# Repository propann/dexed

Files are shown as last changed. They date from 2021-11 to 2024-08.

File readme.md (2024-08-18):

> NOTE: Microdexed-touch is capable of generating audio with a large dynamic range, the extremes of which can cause damage to loudspeakers or other components, and also to your hearing.
> Please be specially careful when activating the MultiBand Compressor. Depending on it's settings, this easily can increase the perceived output loudness by 10x or even more.

# MicroDexed-touch

<br><p>

<br>
(SLA PRINTED ENCLOSURE, DISPLAY SIZE LEFT: 2.8", MIDDLE: 2,8" and RIGHT: 3.2")
<br><p>

<br>
(PCB BASED FRONT/BACK PANEL, DISPLAY SIZE LEFT 2.8" and RIGHT 3.2")
<br><p>
## This is MicroDexed with TFT Touch Display, graphic UI and sequencer

### This build requires a Teensy 4.1,  PCM5102 Audio Board, 320x240 ILI9341 SPI Display with Capacitive Touchscreen, a serial Flash Chip  (and a PSRAM Chip for custom samples).
<p>

MicroDexed started as a Teensy based, 6-operator-FM-synthesizer. The first generation is still maintained at: [https://codeberg.org/dcoredump/MicroDexed](https://codeberg.org/dcoredump/MicroDexed)

Compared to the first generation, MicroDexed-touch offers a lot of new features/improvements:

* The Flash Chip is presoldered on a small PCB attachment for <2$.

* "Large" Graphical Interface, view and edit multiple Parameters in one Screen

* Use external MIDI gear over USB or Mini TRS Jacks (DIN MIDI with adaptor) from 2 x 16 MIDI Channels in the Sequencer

* Map MIDI CC to external MIDI Devices to control Input/Parameters

* Global plate reverb, 2 global delay effects (500ms, with added PSRAM chip 60 seconds or even more)

* Loading, playing and editing multi-sampled instruments or layered instruments in a "live" mode or played by the sequencer. Auto detection sample zones but also can be edited manually. This is early work in progress and currently not stable when using pitch shifting and polyphony

* 2 instances of "Virtual Analog" Monosynths with one OSC, PWM, Multimode Filter and Noise. A lot of useful new sound possibilities.

* 8 voice polyphonic Oscillator, based on the code of Mutable Instruments - Braids. No wavetables but added individual envelopes and multimode filters for all voices
 
* Much improved Sequencer with 8 Tracks, 16 Step Patterns, 16 Step Pattern Chains, up to 16384 Song Steps, Arpeggiator with 1/8 - 1/64 Steps, Arp Patterns including Euclidean settings, Pitched Drum- and Instrument Sample playback

* The sequencer can also play chords of various types, stacked up to 7 notes, using only a single sequencer track

* Global Mixer View with all Channels

* Multiband Master Compressor with 4 bands

* Sample Management from SD-CARD and SPI FLASH/PSRAM, samples can be loaded from SD-CARD to PSRAM during runtime.

* Touch Mute Matrix for live / realtime performance

* Tracker View (Editor) - work in progress

* Track Print/Recording - work in progress

* Remote control in web-based 1:1 UI with added features (filemanager,filetransfer, screenshots etc.) Work in progress - connected to PC via Teensy MicroUSB Connector

[https://www.youtube.com/watch?v=AkmqZVpW2Vg
](https://www.youtube.com/watch?v=AkmqZVpW2Vg)
by Floyd Steinberg
<br>
<p>

[Part1/2](https://www.youtube.com/watch?v=v6thf0vhRxU)
by fellpower (german language)

[Part2/2](https://www.youtube.com/watch?v=wfSquKaAqik)
by fellpower (german language)

### YouTube playlist about the development:
[https://www.youtube.com/playlist?list=PLHTypoMU1QoGOXPli8bjR6MknPiQpubHl
](https://www.youtube.com/playlist?list=PLHTypoMU1QoGOXPli8bjR6MknPiQpubHl)

## If you want to donate to this project, please check out this link:

<a href="https://liberapay.com/positionhigh/donate">Donate using Liberapay</a>

### User Chat groups

[https://discord.gg/XCYk5P8GzF](https://discord.gg/XCYk5P8GzF)

[https://matrix.to/#/#microdexed:matrix.org](https://matrix.to/#/#microdexed:matrix.org)

### PCB is available from PCBWAY

If you register and pay as a new user at PCBWAY with this Invite link, you should get $5 "New User Free Credit" - so you can order 5 PCB pieces for "free", except shipping and customs cost etc.
    
[https://www.pcbway.com/setinvite.aspx?inviteid=565384](https://www.pcbway.com/setinvite.aspx?inviteid=565384)

<a href="https://www.pcbway.com/project/shareproject/MicroDexed_Capacitive_Touch_64970fee.html">PCB from PCBWay</a>

<br>
<p>

## WIKI

Installation / BOM / Compile Instructions / 3D printer files / FAQ / Changelog / News / Troubleshooting etc.
<br>
[https://codeberg.org/positionhigh/MicroDexed-touch/wiki/?action=_pages](https://codeberg.org/positionhigh/MicroDexed-touch/wiki/?action=_pages)

## License

This is a port of the original Dexed/msfa engine (see https://github.com/asb2m10/dexed and https://github.com/google/music-synthesizer-for-android) to be used on a ~~Teensy-3.6 or~~ Teensy-4.1.

MicroDexed is licensed on the GPL v3. The msfa component (acronym for music synthesizer for android, see https://github.com/google/music-synthesizer-for-android) stays on the Apache 2.0 license to able to collaborate between projects.

## Buttons / Encoders

A quick guide how the push Encoders are working:

Usualy [SHORT PUSH] Encoder Left brings you back to the main menu or closer to the main menu one step.

Usualy [SHORT PUSH] Encoder Right selects or confirms an input/menu item/goes deeper into this item.

In most menu settings of dexed, [SHORT PUSH] Encoder Right, switches between the 2 dexed Instances.

In microsynth, [LONG PUSH] Encoder Right, switches between the 2 microsynth Instances.

in Voice select (dexed) : [SHORT PUSH] Encoder Right switches Instances, [LONG PUSH] Encoder Right switches betweens Banks and Sounds. [LONG PUSH] Encoder Left selects/unselects Sounds to the Favorites list.

In Menus that need 2 Encoders, Encoder Right controls Y movement and Encoder Left controls X movement
(for example in Song mode)

## CONTRIBUTING

This project lives from the contributions of C++ developers, testers, reviewers. Please check https://codeberg.org/positionhigh/MicroDexed-touch/issues to help in open topics or add your own Issue or Feature Request.

## SURVEY / POLL: Let us know what you want to see (manufacturing/building MDT)
[https://www.supersurvey.com/poll4335406x48364DD1-136](https://www.supersurvey.com/poll4335406x48364DD1-136)

## SURVEY / POLL 08/2024 feature requests:
[https://qvgopz6on.supersurvey.com/](https://qvgopz6on.supersurvey.com/)

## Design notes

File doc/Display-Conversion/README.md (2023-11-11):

This guide shows how to convert your PCB from resistive touch to capacitive Touch display.
    <br>
    <p> 
    
### SCHEMATICS

CUT all traces/connections shown in RED color.
ADD connections shown in GREEN with wires.
<br>

### SCHEMATICS
<br>

<br> Wiring of old and new display connector 
<p>
    
### PCB FRONT
<br>

<br>
Unfortunately it is required to remove the display connector to reach these 2 traces.
<br>
Use your favorite proven method, how to remove the connector. This could be hot air, a desoldering tool/gun or desoldering wick.
<br>
<p>

### PCB BACK

<br>

<br>
<p>

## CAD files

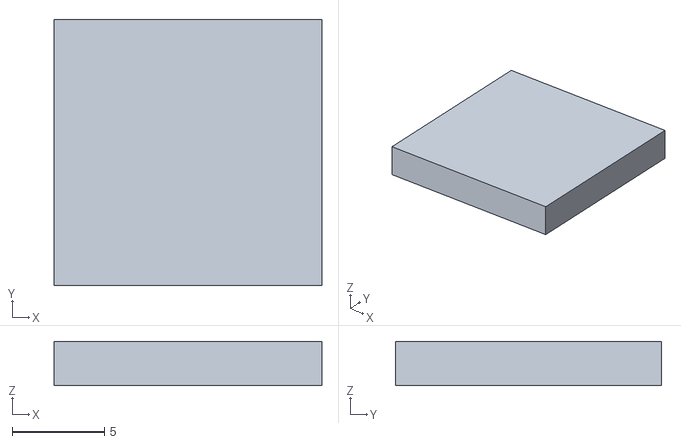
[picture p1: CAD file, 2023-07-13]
doc/Build_InstructionsV2/CASE-SDMOD-LID-COVER.stl
14.5 x 14.4 x 2.40

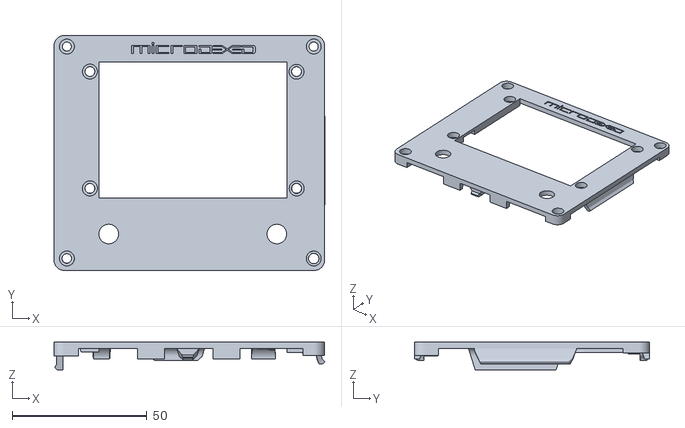
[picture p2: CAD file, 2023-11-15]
doc/Build_InstructionsV3_Capacitive_Touch/LID-capacitive_touch.stl
100.7 x 87.3 x 10.4

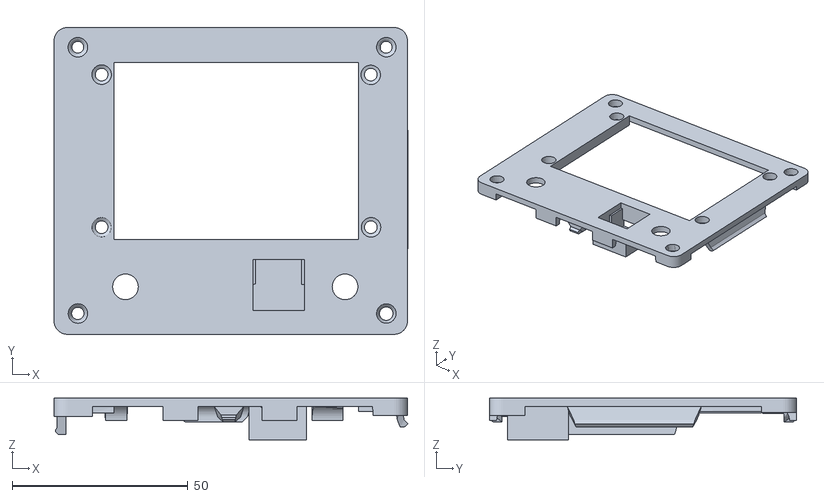
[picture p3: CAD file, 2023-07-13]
doc/Build_InstructionsV2/CASE-SDMOD-LID.stl
100.7 x 87.3 x 11.8

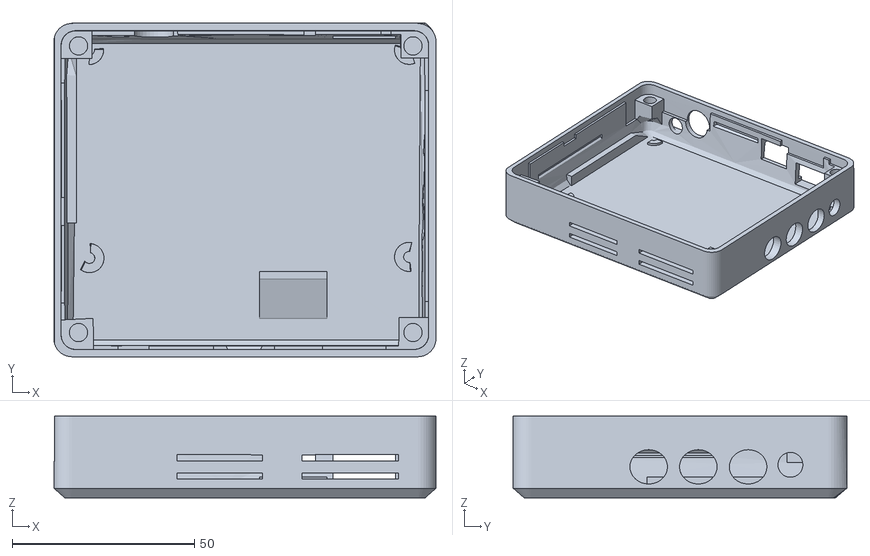
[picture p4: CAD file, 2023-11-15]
doc/Build_InstructionsV3_Capacitive_Touch/BOTTOM-capacitive_touch.stl
104.9 x 91.6 x 22.5

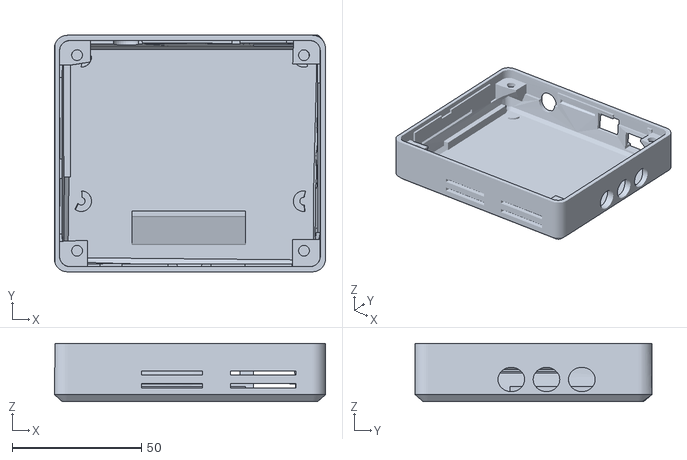
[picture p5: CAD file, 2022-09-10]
doc/Build_InstructionsV2/CASE-BOTTOM-Threaded-Inserts.stl
104.9 x 91.6 x 22.5

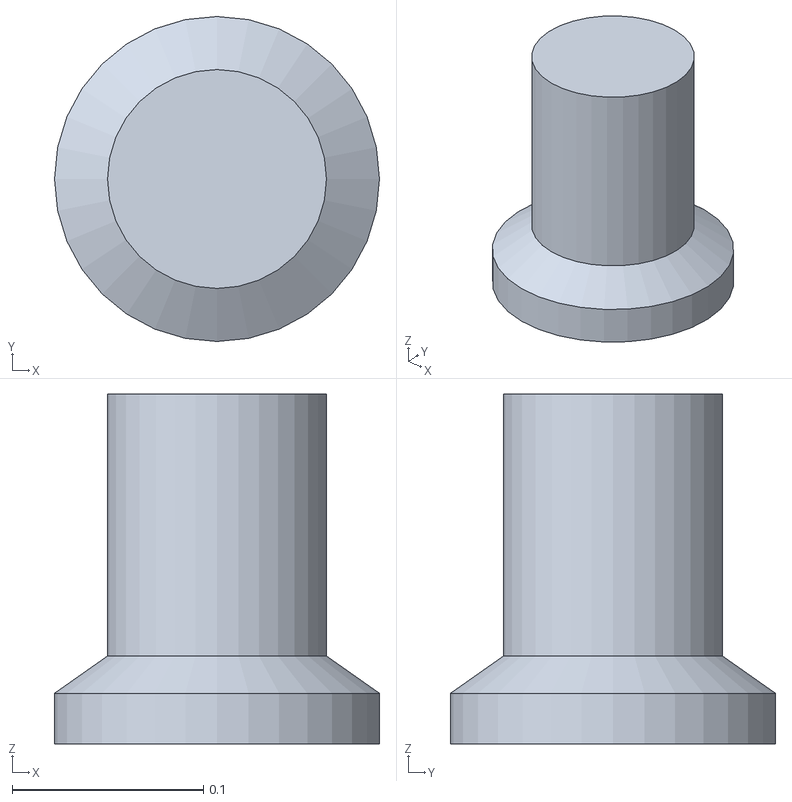
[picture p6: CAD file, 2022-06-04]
doc/Build_InstructionsV2/CASE-KNOB.stl
0.17 x 0.17 x 0.183

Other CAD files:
doc/Build_InstructionsV2/CASE-LID-Threaded-Inserts.stl
doc/Build_InstructionsV2/CASE-BOTTOM.stl
doc/Build_InstructionsV2/CASE-LID.stl
doc/Build_InstructionsV2/CASE-BOTTOM(old).stl
doc/Build_InstructionsV2/CASE-LID(old).stl
doc/Build_InstructionsV2/CASE_BOTTOM.stl

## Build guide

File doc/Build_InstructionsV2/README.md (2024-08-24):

02/07/2024:

- [x] There is a new option to use a 3.2" display instead of the 2.8" display. The matching enclosure lid(s) are currently in testing. Firmware between both of the screens is identical, the only difference is the size.

17/09/2023:

- [x] Updated to capacitive touch display. This is MUCH more responsive.
Note: It is possible to modifiy the current mdt pcb to fit this display. However this requires cutting 2 traces that are below the display connector on the mdt pcb. I do not suggest to make this modification if you don't have advanced skill in desoldering and soldering components with multiple pins.

<br>
<p> 

> NOTE: Microdexed-touch is capable of generating audio with a large dynamic range, the extremes of which can cause damage to loudspeakers or other components, and also to your hearing.
> Please be specially careful when activating the MultiBand Compressor. Depending on it's settings, this easily can increase the perceived output loudness by 10x or even more.

<br>
<p> 

### Build instructions
<br>

<br>

<br>
PCB Front (Capacitive touch)
<p> 
<br>

<br>
PCB Back (Capacitive touch)
<p>
<br>

<p>

**If you want to donate to this project, please check out this link:**

<a href="https://liberapay.com/positionhigh/donate">Donate using Liberapay</a>
    
**PCB is available from PCBWAY**

If you register and pay as a new user at PCBWAY with this Invite link, you should get $5 "New User Free Credit" - so you can order 5 PCB pieces for "free", except shipping and customs cost etc.
    
[https://www.pcbway.com/setinvite.aspx?inviteid=565384](https://www.pcbway.com/setinvite.aspx?inviteid=565384)

<a href="https://www.pcbway.com/project/shareproject/MicroDexed_Capacitive_Touch_64970fee.html">PCB from PCBWay</a>

<br>    
<p>

> 25/07/2024:
If you do not want to solder the Teensy pins by yourself, or the (optional) PSRAM chip, you now can order it from https://protosupplies.com/product/teensy-41-microdexed/ fully soldered and tested, specially for MDT. (with or without PSRAM)


<br>    
<p>

### DIY Instructions without presoldered parts/pcb

<br>    
<p>
Let's begin with the resistors. You need 4, the values are printed on the board and are also listed in the BOM. 2x 47 Ohm, 1x 220 Ohm, 1x470 Ohm. For resistors, it does not matter, in which direction you put them in. At the botton, put in the 1N4148 diode. Make sure the cathode is pointing to the left side.
    
<br>
<p>
This is the 6n138 optocoupler for MIDI. Make sure pin 1 is on the top left. Your chip will either have a notch at the top side or a circle mark at the first pin. You can use an old-school IC socket, solder it in directly or use a socket with (round) precision pins. All of these 3 methods should work fine.

<p>

<br>
(Capacitive touch)
<br>
<p>
The location of the resistors and the diode is slightly different on the newer capacitive touch pcb. Otherwise, the same instructions are valid as for the previous version.
<br>
<p>
<br>

### MAIN PIN HEADER / SOCKETS
    
<br><p>
For the Teensy, the PCM 5102 and the external Flash Chip, we will use pin socket rows instead of IC sockets. The sockets will be soldered to the main PCB.<p>
 
    
As the counterpart, we will use traditional rows of pin headers with the pins of the short side of the plastic spacer snipped off. 
<br>We keep only the side with the longer pins.
<br>
Since the top side of Teensy will be blocked by the plastic spacers, you solder the pins on to the bottom side of Teensy. This is the reason, why the pins are seemingly 2-3mm longer than they need to be for the sockets but the soldering will take up (some) of this extra space.<p>

 
    <br>
 For the Teensy we need 2 pieces of 24 pins.<br>
 
<p>
So for both rows, leave the plastic spacers exactly where they are at factory and snip off the short pin side, directly above the plastic spacer. <p>
This is tedious. Take your time and take breaks when necessary.
<br>
    
Please take care to not hurt yourself or others while you snip the pins. These pins are sharp when cut and will fly off unpredictably if you are not careful. 
<br>Place yourself so that the cut pins will not fly in your direct direction and use eye protection so nothing can happen in this process.

 
<p>
After the 2 long rows are cut like in the pictures above, we will do the same procedure to a much smaller row for the flash board, 2 for the PCM5102 and the USB Host Connector.
<br>Note that we are not connecting the SCK pin for the PCM5102 so no pin/header is required there.
<p>



<br>
<p>
    The Display uses a "normal height" connector, DO NOT solder in a low row socket there.
    <br>

   <br>
    The remaining headers/jumpers are regular pin headers, you do not have to cut anything or do anything unusual here.

<p>


 <p>

     
For the 2 encoder connections, it is advised to use vertical pin headers - Also, depending on your encoders, for example if they have a small PCB on their bottom to connect the pins instead directly to the decoder, it might be a good idea to solder the pin headers very lowly as seen in this image.<p>
This way they will use the free space "above" the encoder's PCBs and won't collide with them.  
<p>

### ENCODERS
<br><p>

    <br>
    Use standard dupont connectors for the encoders. 1 pin is ground, then the 2 encoder pins, then the last pin for the button.
> If you are using encoders that come on a small pcb with resistors located at the bottom side and you experience unwanted "button push" events or other wrong encoder behaviour, try to remove any resistors from the pcbs. In fact it would be even better to remove the whole PCB and just use the encoders alone. This will prevent the collision with the SD Card in the Teensy, located very closely when you do not remove the small PCB. The resistors aren't neccessary as debouncing is done in software and if you keep them, they are known to make make more problems, than they help. When your encoder does not have a common ground (gnd) pin for encoder + button function but has seperate gnd pins for them, you can bridge both gns pins directly at the encoder.
>
<p>

<br>
<p>

<br>
(Capacitive touch)
<br>
<p>
The small 4 pin row between the 2 large Teensy pin rows is for USB MIDI HOST. Do not forget to put in the socked and also the counterpart pin headers on the Teensy.
<br>
<p>
Put in the sockets on the PCB and test fit with the Teensy if everything lines up before you solder the sockets and pin rows.
<br>
<p>
It is a suggestion to solder only the first and last pin, then every 4-5 pin of every row, test if it fits and then solder all remaining pins.
<br>
<p>
The capactive touch pcb is identical, however there is an option to add buttons for soft-power and a program-button. The program-button really is only required when something during firmware flashing goes wrong. In this case it is more convinient that the button is reachable without opening the enclosure. The soft-power is mainly useful when using mdt from an optional battery.
<br>
<p>

<br>
Teensy with pin headers
<p><br>

<br>
Teensy with pin headers and sockets loosely attached to test fit.
<br><p>

### AUDIO
<p>

  
<p>
Do the same kind of connector for the PCM5102 Board. Snip of the short side of the header pins. Do no connection for the SCK pin to the main PCB. Instead, close the 2 small pads on the top side to force SCK to ground - This will tell the PCM5102 to run it's own, internal clock signal.
<b>

 
<p>
    
If any of the solder bridge pads on the backside come closed by factory, remove all of them with desoldering wick or your preferred  desoldering tool/method. 
<b>
    
> If you get distorted/garbled audio, try to solder the bridges 1,2,4 to LOW , middle pad + right side and leave pin 3 without connection to LOW or HIGH. Pin 3 will be controlled by the Teensy for muting control.
> 
    
<b>  
 
<p>
    
<br>   
Front view with pin headers attached
<br>  
  
<p> Top view with pin headers attached

<br>  
  
<p> Flash board attached to main PCB
    
<br>  
  
<p> Flash board attached to main PCB
<p>
<br>
    
### FLASH chip
    
<p>


    
Instead of manually soldering the Flash Chip to the Teensy Audio Board as we did in the previous generation, we go for this plug-and-play, 2$ board that already has a Flash Chip soldered on by factory. So you only need to solder standard size pins/connectors.
Do the same procedure as for the Teensy for the connection to the main PCB. Use pin headers, leave the plastic spacers exactly where they are at factory and snip off the short pin side, directly above the plastic spacer. 


<p>
    Flash board with pin headers soldered, backside
<p>    

    
<p>
Flash board with pin headers soldered, frontside
<p>

<p>
Flash board with pin headers soldered, frontside
<p>
    
<p><br>
    
### DISPLAY
    
<p><br>

<br>

The display connector uses a standard part (normal height) , not the half height connector as in the previous version.
<br>
    However we do use them now as sockets for the Teensy + Audio Board instead. (Without any stacking)<br>

<br>


<br>


<br>

The connector should match up with the pin header that the display comes with by default.<br> 
It does not matter if there is a small gap between the lid/display and the pin socket.
<br><p>
> There might be a small offset, depending on 3dprint, how much solder you have used on the audio board pin rows etc - this will mostly be influenced by how tight you screw on the display to the lid in a later step. 
> 
<br>
There are various versions/kinds of this display on the market.
If your display is working but your touch screen input is reversed/mirrored on one or both directions, you can change it in system - misc settings.
 
<br><p>
Regardless of which display is used (2.8", 3.2", capacitive or resistive):

**Take off the metal lid from the SD card reader on the TFT backside. These larger type of SD card are outdated and we already have a MICRO SD Card reader available on the Teensy. 
<br>If you are sure you do not need it in the future, you can quickly snip it off at it's 4 holding/soldering pads with a small cutting tool.**
<br>

> **To avoid any unwanted electrical contact on the bottom side of the TFT to the teensy pin headers, you should put a non conductive layer between them. Electrical tape, 1-2 layers, should be sufficient.**
>    

> **Before complete assembly, visually check that none of the components on the MDT board are touching the bottom of the display board. There should be sufficient clearance from all components when the SD reader is removed from the bottom of the display.**
>  

### MIDI and AUDIO AMP Jumpers (MDT Capacitive Touch)

<p>

<br>
If you have added the optional Headphone Amplifier, set the 3 AMP Jumpers to the ON position.
<br>

<p>

<br>
If you have not added the optional Headphone Amplifier, or want to bypass it, set the 3 AMP Jumpers to the OFF position.
<br>

<p>


<br>
If you want to use TRS JACK TYPE A MIDI devices on Input and Output, place jumpers to the A position. 
<br>

<p>

<br>
If you want to use TRS JACK TYPE B MIDI devices on Input and Output, place jumpers to the B position. 
<p>
<p>

<p>

<br>

### OPTIONAL PINS / Jumpers / Connectors on the right side of MDT PCB

Usualy you do not have to place any jumpers here and do not have to make any connections.
Concider this jumper block as optional when you want to add any customized code, external rechargeable battery board etc.
If you do have any S/PDIF outbord equipment, you might want to use the digital output S/PDIF pins to connect to your digital mixer or other digital input device to get a perfect, digital clear 16bit, 44Khz stereo output from MDT master output.

<p>
<p>

### FIRST TEST
<p>
At this stage, it should be possible to do a first test. 

> You do not need to put in a SD CARD with the preset files copied to it. MicroDexed should at least boot up and the menu/encoders can be tested in the menu - however it will take a few more seconds than usual to start up, if there is no SD CARD with valid files present.
>

<br>
<br>

<br>

<br>
<p>
    
### CASE/ENCLOSURE
<br>

<br>
    
There are 2 different versions provided for self printing you a simple case for MicroDexed (or you can use your favorite 3d printing service to do that).
<p>
Also you can order a printed SLA case from pcbway:<p>
  

<br>

<br>
    <p>
You can get SLA printed parts from pcbway with excellent quality. The shopping and download links are at the bottom of this main page at pcbway:
<br>

[https://www.pcbway.com/project/shareproject/MicroDexed_Capacitive_Touch_64970fee.html](https://www.pcbway.com/project/shareproject/MicroDexed_Capacitive_Touch_64970fee.html)

<p>
Print quality is much higher, of what you can expect from a home made PLA or SLA DIY print.<br>
 Since SLA Prints can not be melted by a hot iron, this version has some special modification that will perfectly fit M3 threaded inserts to be superglued in, with 1-2 drops.
<p> The SLA version also has some extra details, that are not possible to print by a PLA printer, like the MDT Logo.   
<p>
<br>
If you do not want to use a printed enclosure, there is an alternative solution available from pcbway that consists of 2 bare pcbs as a top and bottom part that is screwed together with M2 + M3 screws, externders and some lock nuts. 
<br>
    <p>The following video demonstrates how this is intended to work. 
<br>
 Similar as for the printed case, this option is also available for the 3.2" display. In both cases, only the top plate/ top lid needs a different part to fit the display. The bottom part is identical for the 2.8" and the 3.2" screen, no matter if it is printed or the pcb based alternative.

[https://www.youtube.com/watch?v=sjoiCc8XJiM](https://www.youtube.com/watch?v=sjoiCc8XJiM)
<br>
<p>
Here are the links for the pcb-based enclosure:
<br>
Front:
<br>
https://www.pcbway.com/project/shareproject/W424985ASE20_pcb_enclosure_front_plane_c17b035e.html
<br>
Back:
<br>
https://www.pcbway.com/project/shareproject/mdt_pcb_enclosure_bottom_plane_39654ff7.html

<br>
<p>

### 3D PRINTING TIPS - Valid for both case versions
    
<p>
<br>

<br>
    If the case dimensions do not fit 100%, check if your slicer has an option as in the screen above.
<p>
     
<br>
    If you have problems with the case parts coming off the build plate during print, it is recommended to print a brim around each part. This helps a lot to not get any lift-ups during the print, even without any build plate heating.
    <p>
    All STL Files, of both versions, will print without any support structures.
    <p>
<br>
    
<br>
    <p>
        If you have encoders that have a small PCB attached at the bottom, check out that there is no overlap or collision with the SD CARD of the Teensy.
      <br>
        If they do overlap, you might be able to cut/saw the PCBs a bit or just rotate them a few degrees away, like in the picture above.
        <br> 
        
> Observe that nothing touches the SD CARD when you put everything together.
        <br>Do not put any mechanical stress on your SD CARD or sooner or later it will get a fracture and then become unreliable or will stop working completely.
> 
 
### CASE OPTIONS
    
The first case option described here is the improved version, featuring threaded inserts for M3 screws. This makes the overall stability and handling much better since you can open/close the device as many times as you like, without having to rely only on the printed snap-in clips to hold it together.
<p>
Since it is easier to build the previous version with the snap-in clips only, that is still available as an option further down this page.
It is however recommended to build the threaded version, even it needs some more parts and also more effort to put together but it is well worth it.
<p>
To make the instructions less confusing, photos on this page showing a black case are for the snap-case, the photos with the white case are for the improved, threaded inserts version.

<p><br>

<br>
    
### Threaded Inserts Case
    
<p><br>

<br>
This case has 4 mounting posts, 1 at each corner of the device. 
<p><br>

<br>
These are the inserts we are using, the M3 x 5.7 x 4.6         
<p><br>

<br>
Maybe it is possible you can get a smaller ammount of them (since you only need 4 pieces) but it might easier to get a full set like this from Amazon, ebay etc. If you do any kind of 3d printing, this is a package you can use for a lot of other projects, too. I will add links to a set like this in the BOM.            
<p><br>

<br>
Close up mounting post                 
<p><br>

<br>
Each insert has 3 "zones". The zone with the smallest diameter will fit into the case like this.                    
<p><br>

<br>
To drive the insert into the case, you basically heat up your soldering iron to 175-180 degree celsius.
<br>
    
> If there is left residue of solder on your iron, heat it up to your usual soldering temerature first, and clean the iron tip as good as possible. It must be avoided that you put solder in side of the inserts, by accident.
    
When the soldering iron tip is clean of solder, switch down to a temperature of 175-180 degree celsius and give it enough time to "cool off".
Then push in the insert slowly with the tip of the iron.
<br>
This is a matter of maybe 4-5 seconds. Do not push it in to deeply - it should be flush with the top surface of the mounting post.
    
It should be possible to make some corrections by re-heating but if you haven't any experience with this procedure, it is recommended to practice with at least 1 other printed 3d part (maybe you have some failed prints or test prints from this or an other project).
<br>
The printing time of the bottom case for Microdexed is around 4 hours. So it is a good idea, to have some practice on an other print object, first.
    
<p><br>

<br>
The insert should look similar to this after melting it in.                            
<p><br>

<br>
This is the case with all 4 inserts fitted.                                
<p><br>

<br>
For the screw part you can use M3 x 4 or M3 x 5 screws. It is possible to even use much longer M3 screws - but that only makes sense if you have such already available in front of you - otherwise it is better to go with the M3 x 4.
As a side topic, for the screen attachment, we will use the M3 x 6.
<p><br>

<br>
Various M3 screws from x4 - x24 as a kit from Amazon.                                      
<p><br>

<br>
The head part of the M3 should be flush with the top of the device, after screwed in.                                           
<p><br>

<br>
All case screws in place                                             
<p><br>

<br>
This is the PCB inside the threaded inserts case.
<br>
Notice that the 2 encoders used in the picture had to be rotated a bit, to make space for the mounting posts.
<br>
Depending of the Encoders you are using, this might be necessary, or not.
    
If it seems not to fit, even by rotating: If they come with a small attached PCB, like in the picture, it might be an idea to saw off some empty space from it or remove the small PCB below the Encoder, altogether.
<br>
If you decide to saw off something, carefully check if there are traces on the top or bottom side, that are required. In the sample picture, i have manually connected a ground wire since i saw off the part of it's pcb trace.                                                  
<p><br>
    
Files last updated: 13/07/2023
<p><br>
STL - CASE BOTTOM (threaded insert version):
<br>
https://codeberg.org/positionhigh/MicroDexed-touch/raw/branch/main/doc/Build_InstructionsV2/CASE-BOTTOM-Threaded-Inserts.stl   
<p><br>

<br>
<p><br>
STL - CASE LID (threaded insert version): 
<br>   
https://codeberg.org/positionhigh/MicroDexed-touch/raw/branch/main/doc/Build_InstructionsV2/CASE-LID-Threaded-Inserts.stl   
<p><br> 

<br>

<p><br>
STL - KNOB (two of them are needed):
<br>
  https://codeberg.org/positionhigh/MicroDexed-touch/raw/branch/main/doc/Build_InstructionsV2/CASE-KNOB.stl
  
<br>    

-----
### CASE MODIFICATION (for easy SD CARD access)
<p> 
This section is about a modified LID part, there is no change required for the bottom part of the enclosure.
<p> 
This modification looks a bit hacked and it is, however it is tested about several month now and if you do not care so much about the design or looks, this hack is very useful. There is about no reason to open the enclosure ever again, if you use this lid.

<p>
On our youtube playlist you find a video covering this topic at:
<br>
https://www.youtube.com/watch?v=yFXT1o5kOMk
<p>
There is a about of 1-2mm tolerance about the bottom position of the card slot entry. This is by design since we do not know exactly about the total height your teensy is in the low profile socket. That really depends on your soldering style.
<p>
If you find the bottom position to be too high or low in general, you can edit the .stl file for example with blender to fit your unit. Or let us know in discord chat what you need and we will provide some additional version with maybe 1 or 2 mm height adjustments.

<p><br>

    <br>
    <br>
 https://codeberg.org/positionhigh/MicroDexed-touch/raw/branch/main/doc/Build_InstructionsV2/CASE-SDMOD-LID.stl
<br>

<p><br>

    <br>
    <br>
 https://codeberg.org/positionhigh/MicroDexed-touch/raw/branch/main/doc/Build_InstructionsV2/CASE-SDMOD-LID-COVER.stl
<p><br>

-----

<p><br> 
        
### OLD CASE (without Threaded Inserts, deprecated)
<p><br>

    <br>
    This is the bare bottom case. With the spacers of the case itself and the height matching the display's the PCB should not move in any direction when put together.
<p>
    
<br>
      
<br>
    
<br>
3D print (STL) files:
<br>
 https://codeberg.org/positionhigh/MicroDexed-touch/raw/branch/main/doc/Build_InstructionsV2/CASE-BOTTOM.stl
<br>
 https://codeberg.org/positionhigh/MicroDexed-touch/raw/branch/main/doc/Build_InstructionsV2/CASE-LID.stl
<br>
  https://codeberg.org/positionhigh/MicroDexed-touch/raw/branch/main/doc/Build_InstructionsV2/CASE-KNOB.stl
<br>   
  
   <br>
  

<br>


    <br>
    Slide the PCB+Teensy assembly in the lower case. You might have to tilt a bit to the right side of the audio/midi connectors.
<p>
<br>

<p>
        

<br>
PCB with all on board components ready
<p>
<br>


<br>

<br>
    
### Final Assembly (depreciated case)
<p>
<p><br>

<br>
    
### Final Assembly (Threaded Inserts Case)

<p>

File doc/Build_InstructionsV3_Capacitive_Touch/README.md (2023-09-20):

>This page is about the next/upcoming version of MDT with a capacitive touch display instead of the previous resistive touch. The touch input quality is enhanced drastically by this change.
    
<p> 
<br>
  Until this transition is complete, the full, previous build instructions are (and will stay there) here:
<br>
https://codeberg.org/positionhigh/MicroDexed-touch/wiki/Build-Instructions

<p> 
<br>
For the moment, this page will only document the changes that are in progress.
<p> 
<br>

This update will feature a  better display and touch input at a similar price. This display offers capacitive touch and is MUCH more responsive as the current default display. 
<br>However, so far only one two source of this display type is available and the order amount seems to be limited to one screen only per order. (might have changed in the last weeks)
<br>
Display sources:
<br>
https://www.aliexpress.com/item/1005005926026997.html?spm=a2g0o.cart.0.0.4c6e4ae4FvwMuX&mp=1
<br>
https://a.aliexpress.com/_mtbH3VY
<br>
Note: It is possible to modifiy the previous mdt pcb to fit this display. However this requires cutting 2 traces that are below the display connector on the mdt pcb. I do not suggest to make this modification if you have not somewhat advanced skill in desoldering and soldering components with multiple pins.

It will take some time to figure out software and hardware changes and the waiting for the arrival of a new pcb test version. I estimate this can take severals weeks or even months, so progress on this topic is estimated about end of 2023. 

<br>From the software side, this display, including touch is already working, at least in a basic way. Some color inverting issues and the necessary changes for the new touch are already in the downloadable source. There will be further fixes and enhancements when the first prototype pcb will arrive. 


<br>
Updated PCB front and backside
<p>


<br>
Lid-Changes
<p>


<br>
Lid-Changes
<p>

<p><br>

<br>

STL - CASE LID (capacitive touch): 
<br>   
https://codeberg.org/positionhigh/MicroDexed-touch/raw/branch/main/doc/Build_InstructionsV3_Capacitive_Touch/LID-capacitive_touch.stl   
<p><br> 

The bottom part of the enclosure is supposed to be the same as it was before. You can find it in the previous full build guide:
<br>
https://codeberg.org/positionhigh/MicroDexed-touch/wiki/Build-Instructions
<p><br> 

<p>


<br>
I think the tightness of the top lid is very good. There is only a small strip of light coming in where the nudge for the ribbon connector is located. I am sure this can be further enhanced but for now i will not put a priority there.
<p>

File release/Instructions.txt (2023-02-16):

Installation Instructions

Several binary, HEX Files are provided in the /release folder. For starting, we suggest to flash mdt_default_(latest version number you see).hex

Upload HEX file to your Teensy 4.1:

You just need the Teensy Loader application and your HEX file. 

Get Teensy Loader
https://www.pjrc.com/teensy/loader.html

- [x] connect your teensy to your computer with a known working USB-Micro-B to USB-A data cable.

- [x] launch teensy loader

- [x] Drop the HEX file onto Teensy Loader

- [x] Push the button on the Teensy and Teensy Loader should send the program to the Teensy.

* Copy all Files/Directories from /addon/SD/ to the root of your SD Card (FAT32) and insert the card in SD Slot of the Teensy 4.1

* Power on the Teensy and attach USB MIDI Keyboard (or use the virtual Touch Keyboard and the Encoders to navigate)

* If you have a FLASH chip, go to FileManager, Touch the icon "Copy Presets" and push Encoder R. This will copy all Samples from sdcard/DRUMS to FLASH.

* If you are using the prototype PCB, check out the current state at:
https://codeberg.org/positionhigh/MicroDexed-touch/wiki/Build-Instructions

* if you do not have the prototype PCB but want to get one, you can order it at:
https://www.pcbway.com/project/shareproject/MicroDexed_Touch_current_version_with_PCM5102_d643a695.html

Otherwise, follow the pinout at:
https://codeberg.org/positionhigh/MicroDexed-touch/wiki/Wiring

FAQ:
https://codeberg.org/positionhigh/MicroDexed-touch/wiki/Troubleshooting-Guide-and-FAQ

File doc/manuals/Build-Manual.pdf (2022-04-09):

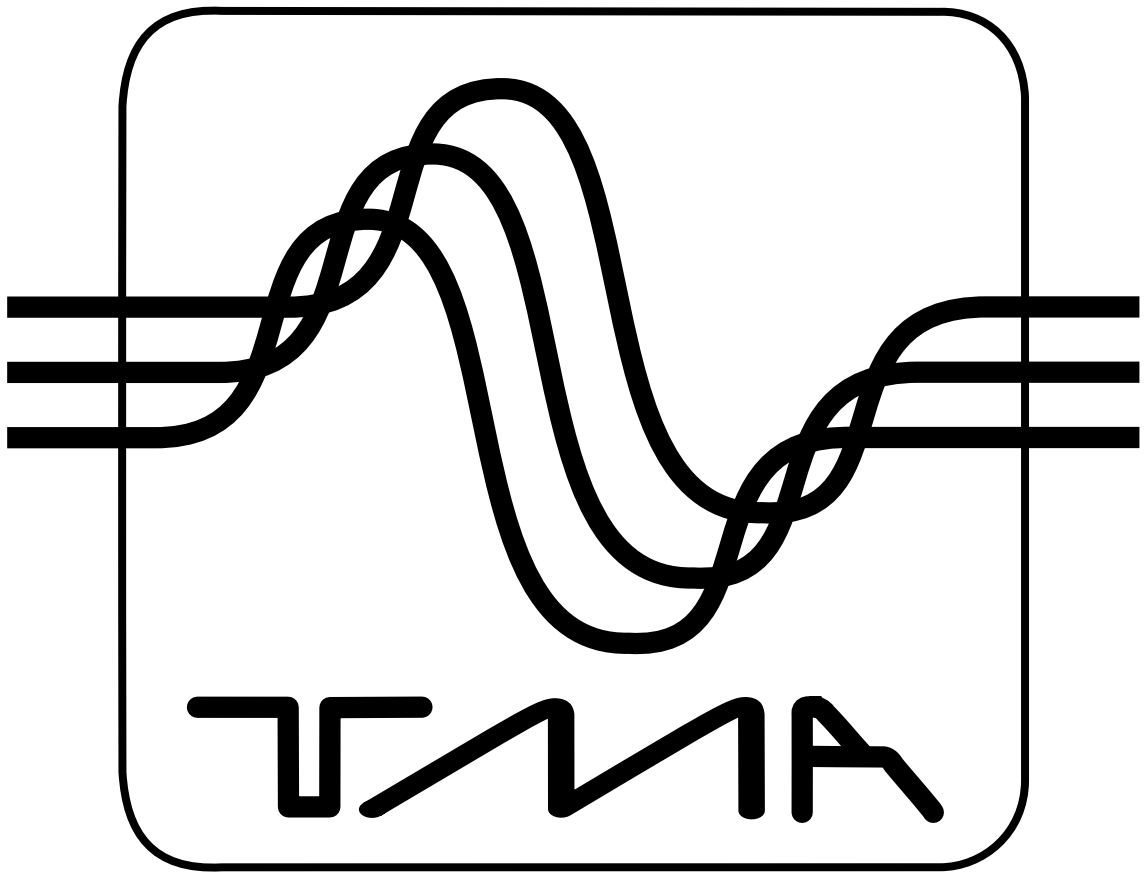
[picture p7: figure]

# TeensyMIDIAudio Build Manual

written by Holger Wirtz and Thierry Pottier

Version 1.1 (July 2020)

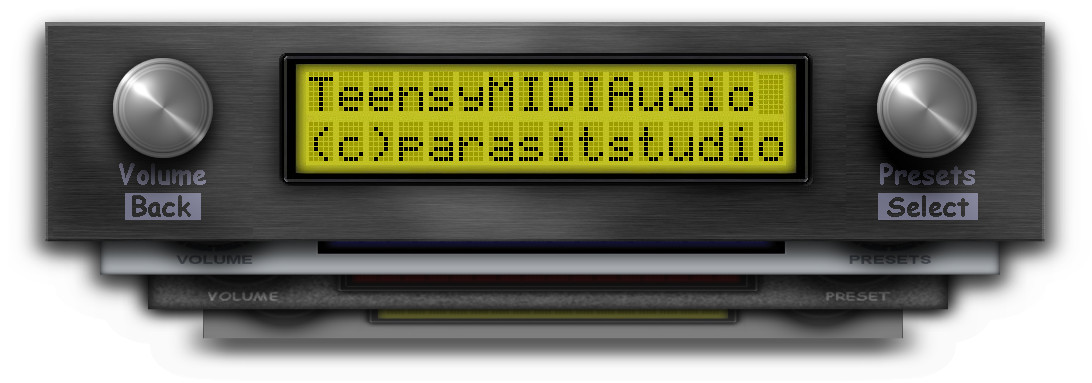
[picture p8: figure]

## What is TeensyMIDIAudio?

TeensyMIDIAudio (also known as TMA) is a flexible kit to build a synthesizer or effects unit based on a Teensy-3.x microcontroller. For example, you can load MicroDexed or MicroMDAEPiano onto your Teensy using the Arduino IDE and then select a MIDI instrument. It has onboard MIDI-IN/OUT sockets (and a MIDI-THRU on pin-headers). Also it supports the Teensy-audio-shield (Revision C) and has RCA connectors for audio input/output. For the power connection a USB-B socket is used and if connected with an adapter cable this socket can also be used for programming then Teensy. Another USB-A socket can be used for USB-host connections towards the Teensy-3.6.

## Requirements

Making a TeensyMIDIAudio board is not very difficult, but you should consider the following:

You should've soldered something before, preferably a small kit. Without some practice you will get problems with bad soldering joints. Errors like this are always very difficult to find if you have not worked properly. Instructions on how to solder and which tools to use can surely be found on the Internet.
You need time! Someone with a lot of experience and practice can finish the whole kit in 2 hours. But if you don't take enough time, there is a high risk to fill something wrong or to create bad soldering joints.
You need good tools. Good doesn't always mean expensive. But don't try to work with unsuitable tools, because it may also lead to problems.

## Tools

Soldering iron: It is best to use a temperature-controlled soldering iron or a station with about 40 watts of power. Never use soldering tips that are too large or a soldering iron with a large capacity. Soldering tin
(Small) Side cutter
"Helping hand" or heat resistant fastening material
Stripping tool
Hot air gun for shrinking tube

## Build

The printed circuit board has numerous optional components that only need to be mounted in certain cases. This guide shows you all possible options and indicates whether steps are optional or recommended. All steps without further hints are necessary.

It is also possible to equip the board with a PT8211 I2S audio chip instead of the Teensy Audio Shield. This option is not shown here. If you want to use this option, please take a look at the schematic or ask directly via email or in the forum.

The build process is organized into several steps. Each step is on one page with pictures showing the relevant changes. It is good practise to take a short break after each step. For steps in which you have to solder very much (like the IC sockets) you should take breaks in between.

Be careful when soldering on the Teensy audio board! You should take care not to stay too long on one soldering point. Again, take breaks to let the soldering joints cool, so that the chip on the board will not be damaged.

If you are unsure or the manual is not precise enough or misleading, please ask by email or forum before doing something wrong!

Note: The photos show a mounted SMD component (type PT8211) and resistor R2. These are not necessary and not pre-assembled.

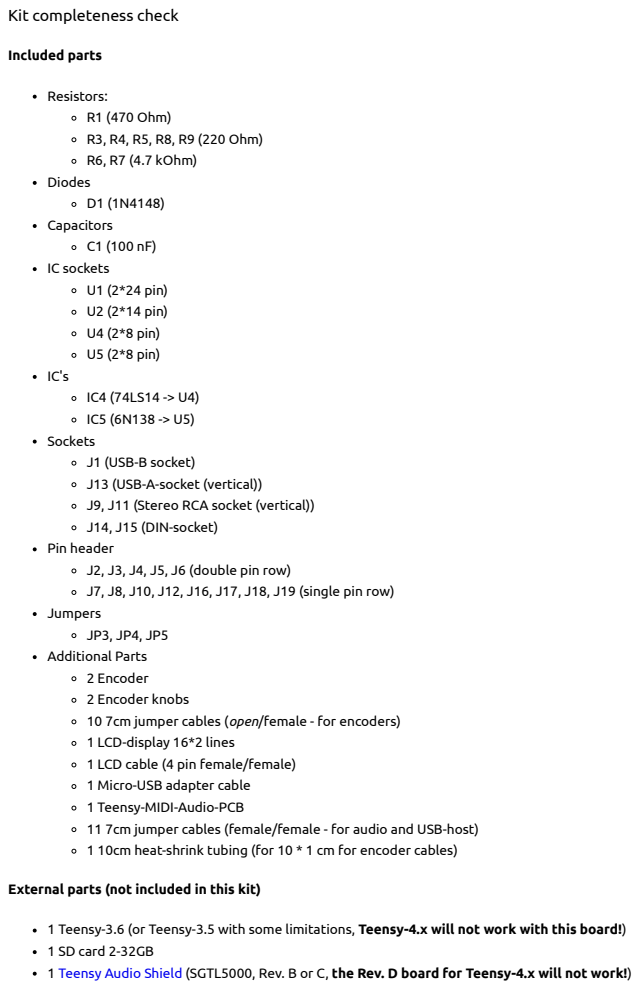
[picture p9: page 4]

Resistors:
R1 (470 Ohm)
R3, R4, R5, R8, R9 (220 Ohm)
R6, R7 (4.7 kOhm)
Diodes
Capacitors
IC sockets
U1 (2*24 pin)
U2 (2*14 pin)
U4 (2*8 pin)
U5 (2*8 pin)
Sockets
J1 (USB-B socket)
J13 (USB-A-socket (vertical))
J9, J11 (Stereo RCA socket (vertical))
J14, J15 (DIN-socket)
Pin header
J2, J3, J4, J5, J6 (double pin row)
J7, J8, J10, J12, J16, J17, J18, J19 (single pin row)
Jumpers
Additional Parts
2 Encoder
2 Encoder knobs
10 7cm jumper cables (open/female - for encoders)
1 LCD-display 16*2 lines
1 LCD cable (4 pin female/female)
1 Micro-USB adapter cable
1 Teensy-MIDI-Audio-PCB
11 7cm jumper cables (female/female - for audio and USB-host)
1 10cm heat-shrink tubing (for 10 * 1 cm for encoder cables)

External parts (not included in this kit)

1 Teensy-3.6 (or Teensy-3.5 with some limitations, Teensy-4.x will not work with this board!)
1 SD card 2-32GB
1 Teensy Audio Shield (https://www.pjrc.com/store/teensy3_audio.html) (SGTL5000, Rev. B or C, the Rev. D board for Teensy-4.x will not work!)

1 USB power supply with USB type B connector

Assembling the kit

For the assembly of printed circuit boards you should always start with the flattest components and mount the higher components step by step. On the next pages you will find several steps for the parts in a recommended order.

Diode and Resistors
Capacitor
IC sockets
Double-row pin headers
Single-row pin headers
Sockets
Solder the audio card
Solder USB-Host pin header for the Teensy-3.6 (OPTIONAL) Solder the encoders
Insert the ICs
Insert the Teensy
Connect USB-Host (OPTIONAL)
Insert the audio card
Connect audio card
Prepare and insert SD card (OPTIONAL: only needed for using TMA with MicroDexed) Connect encoders
Connect LCD display
Setting jumpers
Test and trouble-shooting

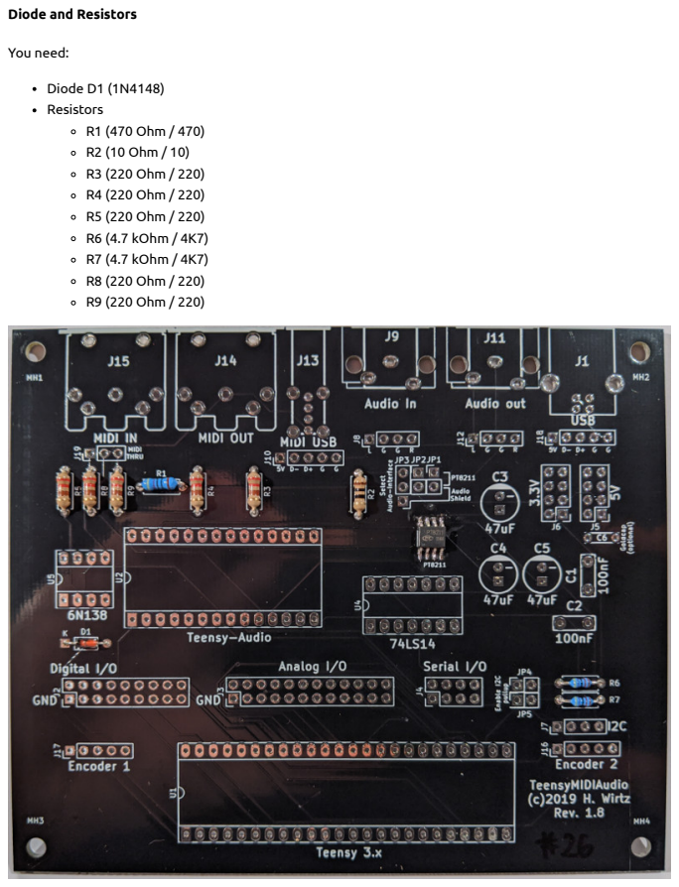
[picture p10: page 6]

Capacitor

You need:

Capacitor C1 (100 nF)

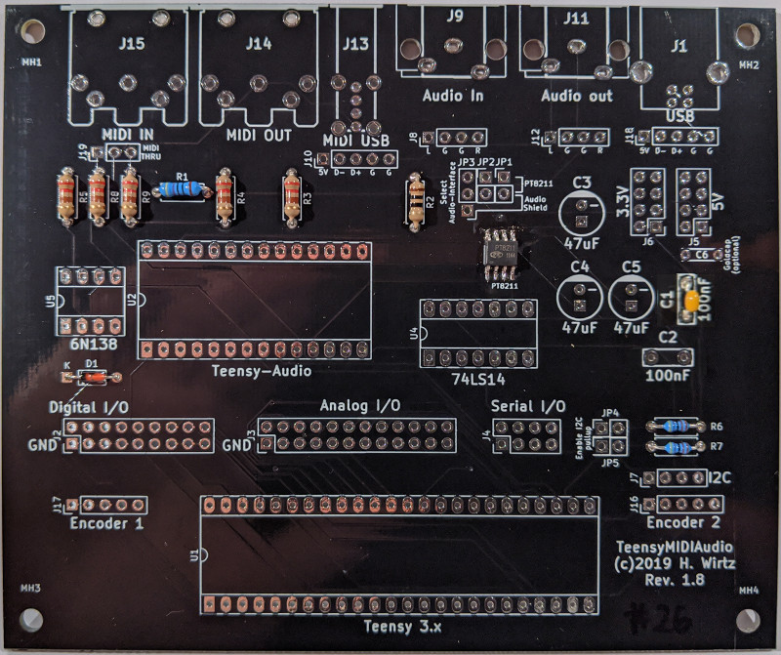
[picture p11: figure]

IC sockets

Note the mounting direction in the IC sockets: If the board is aligned like in the picture below, the notches of all IC-sockets must point to the left.

You need:

U1 (2*24 pin)
U2 (2*14 pin)
U4 (2*8 pin)
U5 (2*8 pin)

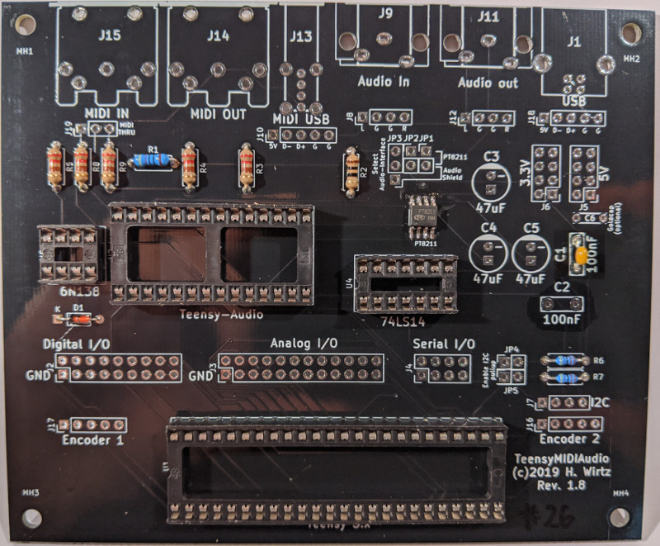
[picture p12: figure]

Double-row pin headers

You have to cut the needed number of pins from the long double-row-headers on your own. Only JP4 is needed, the rest are optional signals and ground pins if you want to extend the hardware by yourself. For more information take a look at the circuit diagram.

You need:

JP4 (2 * 2 pin rows)
J2 (9 * 2 pin rows) (OPTIONAL) J3 (12 * 2 pin rows) (OPTIONAL) J4 (4 * 2 pin rows) (OPTIONAL) J5 (4 * 2 pin rows) (OPTIONAL) J6 (4 * 2 pin rows) (OPTIONAL)

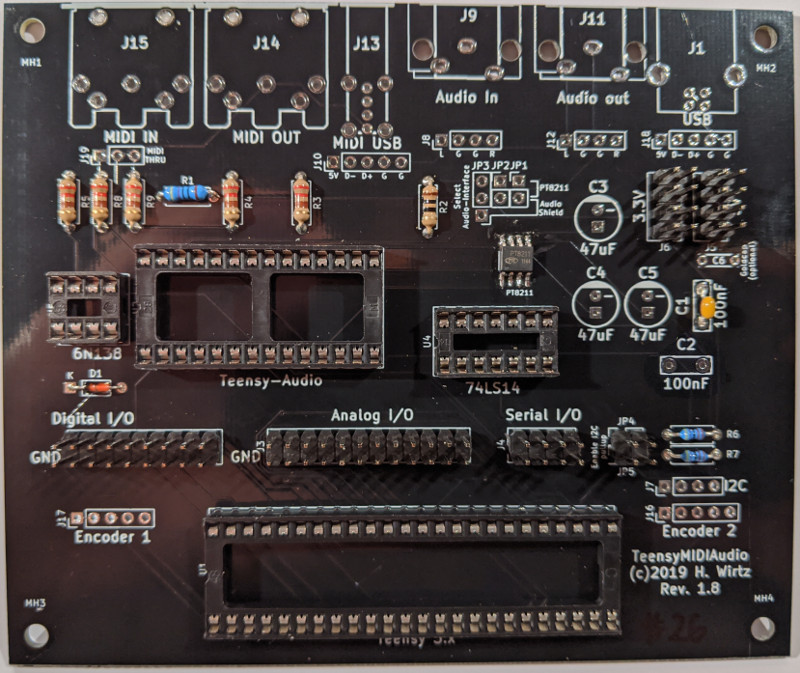
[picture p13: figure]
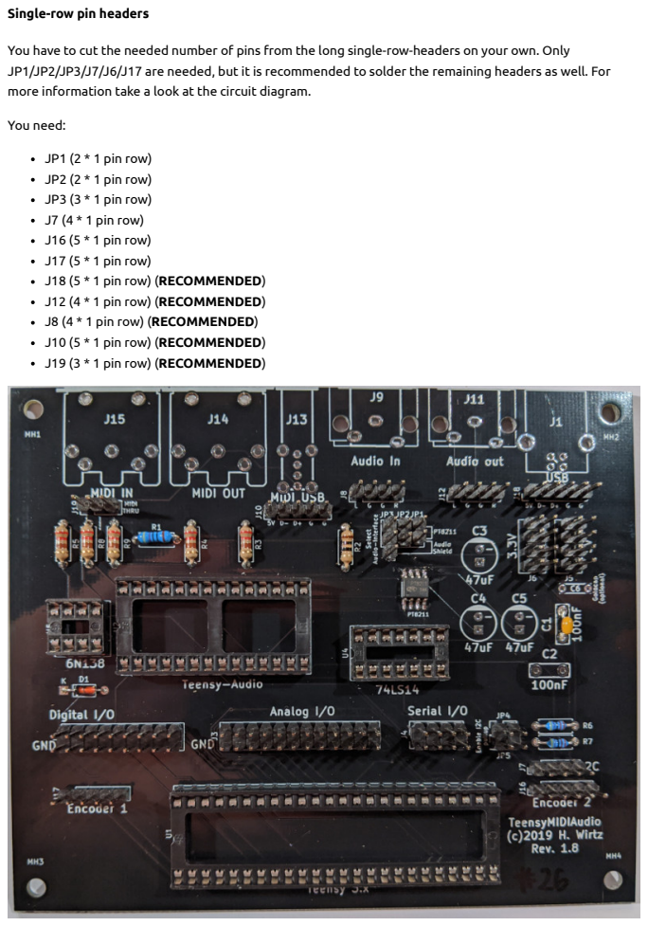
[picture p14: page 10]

Single-row pin headers

You have to cut the needed number of pins from the long single-row-headers on your own. Only
JP1/JP2/JP3/J7/J6/J17 are needed, but it is recommended to solder the remaining headers as well. For
more information take a look at the circuit diagram.

Sockets

Only J1/J11/J15 are needed, but it is recommended to solder the remaining sockets as well. For more information take a look at the circuit diagram.

You need:

J1 (USB-B socket)
J11 (Stereo RCA socket (vertical))
J15 (DIN-socket)
J9 (Stereo RCA socket (vartical)) (RECOMMENDED) J14 (DIN-socket) (RECOMMENDED)
J13 (USB-A-socket (vertical)) (RECOMMENDED)

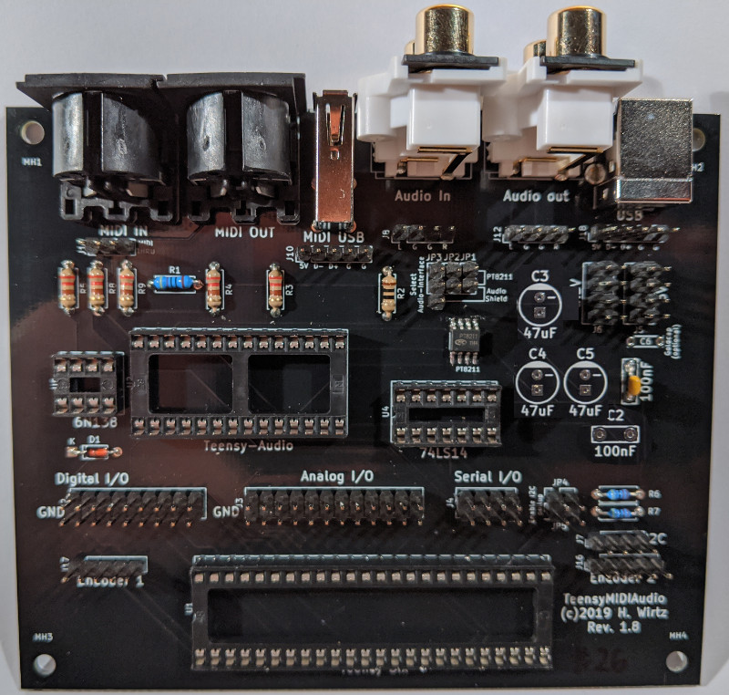
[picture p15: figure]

Solder the Teensy Audio Shield

You have to cut the needed number of pins from the long single- and the double-row-headers by yourself. The 2 * 2 pins are optional and only needed if you want to use the option for audio-input. The 3-pin-single-row header on the right picture (for GND/VOL/3.3V) is not needed.

Be careful not to overheat the onboard chip when soldering the headers. Take a small break after soldering every pin to let it cool down.

You need:

Teensy Audio Shield (not included in the kit) 1 * 3 pin rows
2 * 14 pin single row
2 * 2 pin rows (OPTIONAL)

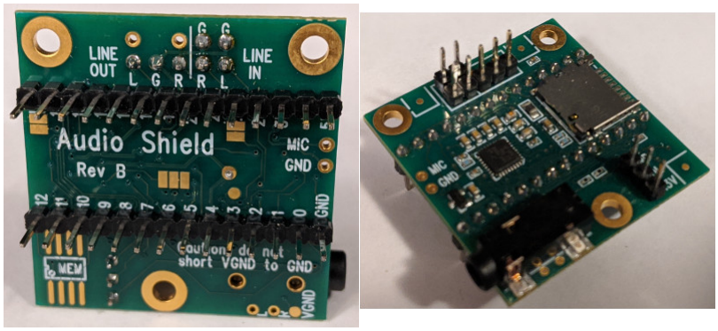
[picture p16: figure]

Solder USB-Host pin header for the Teensy-3.6 (OPTIONAL)

You have to cut the needed number of pins from the long single-row-headers by yourself.

Be careful not to overheat the onboard chips when soldering the header. Take a small break after soldering every pin to let it cool down.

You need:

Teensy-3.6
1 * 5 pin rows

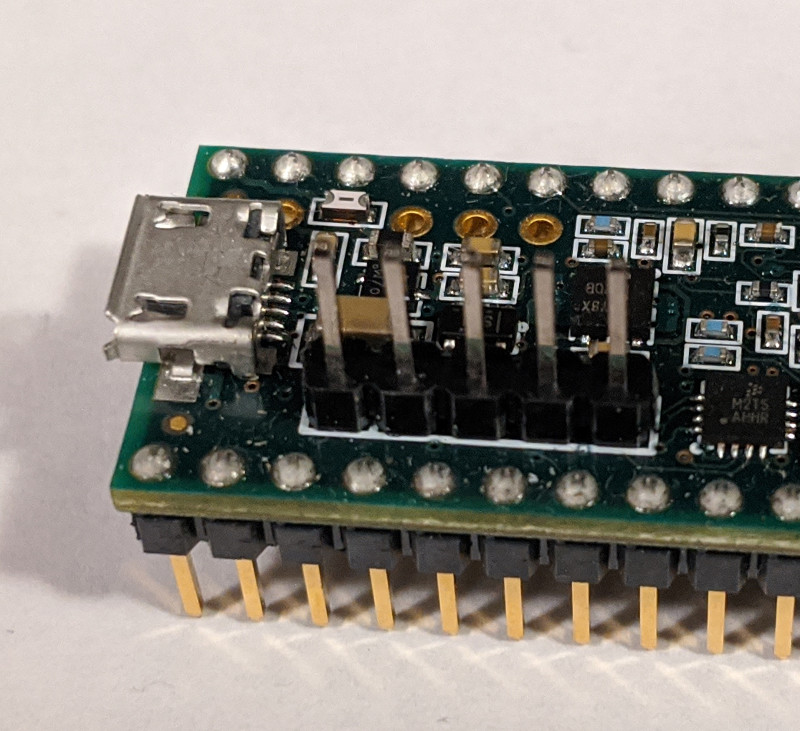
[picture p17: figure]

Solder the encoders

The kit contains 10 wires with open ends. These open ends must be stripped, tinned and soldered. You need 5 wires per encoder. To be on the safe side, heat shrinkable tubing should be put over the soldering joints. For this you have to cut 10 pieces out of the long shrink tube.

You need:

10 7cm wires (open/female)
2 encoders
2 encoder knobs (OPTIONAL) 10 pieces of 1 cm shrink tube

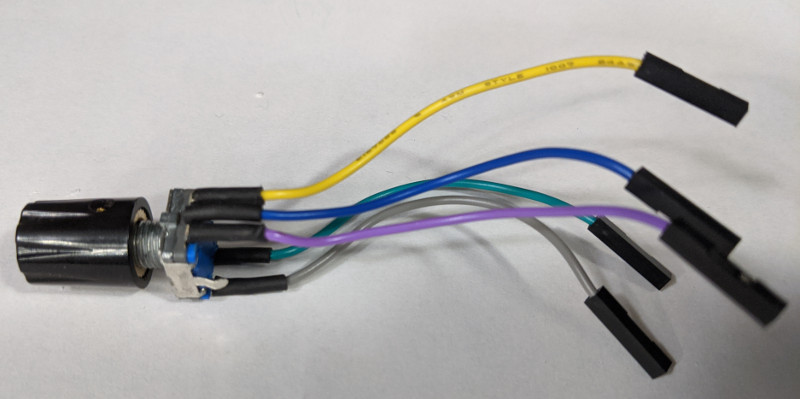
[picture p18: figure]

Insert the ICs

Note the direction in which the two ICs must be inserted: If the main PCB is aligned like in the picture below, the notches of both ICs must point to the left.

You need:

IC4 (74LS14 -> U4)
IC5 (6N138 -> U5)

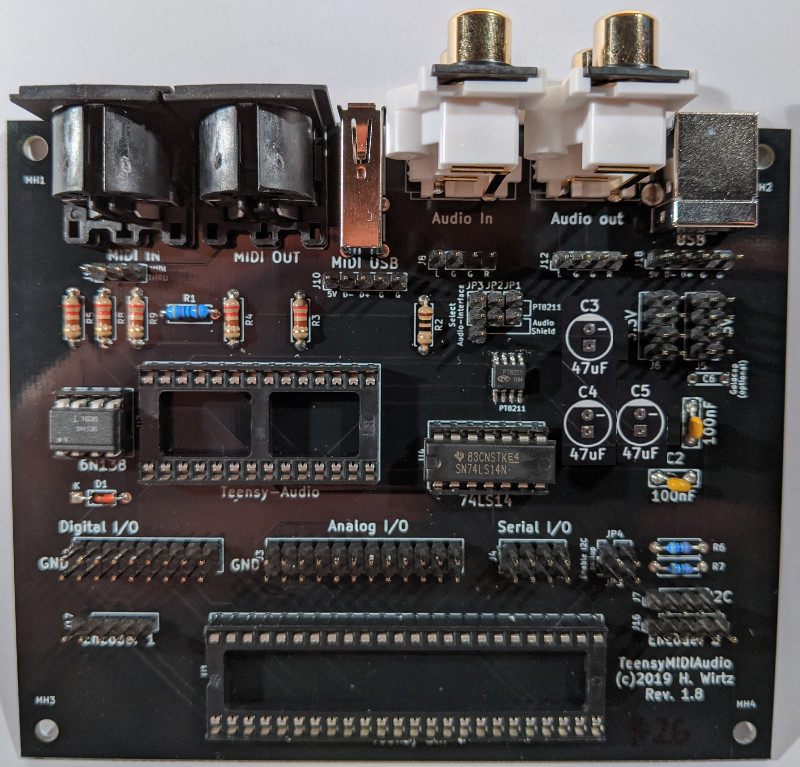
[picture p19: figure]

Insert the Teensy

Note the direction in which the Teensy must be inserted: If the main PCB is aligned like in the picture below, the SD card slot must point to the right. Also connect the USB adapter cable so that the thicker black end of the female connector is located to the right (like in the picture below).

You need:

Teensy-3.x (not included in the kit)
Angled USB micro adapter cable

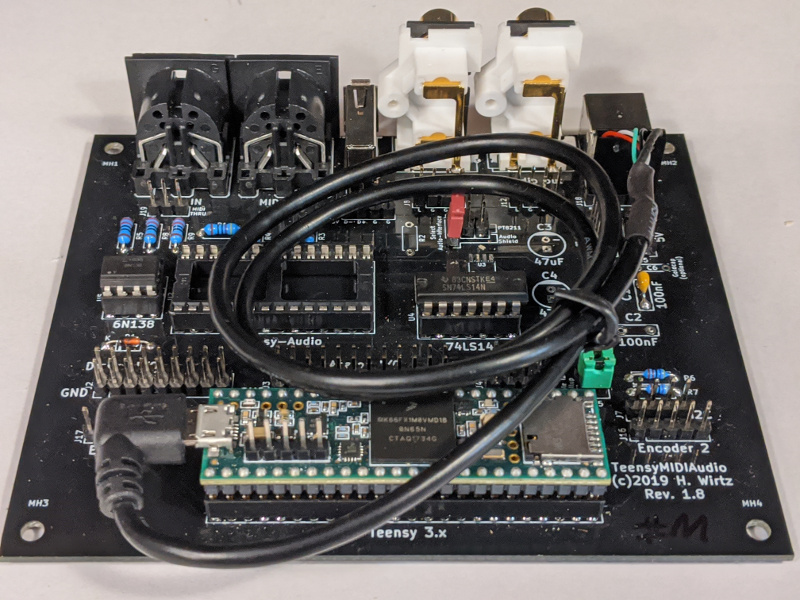
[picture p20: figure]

Connect USB-Host (OPTIONAL)

Connect the USB-host pins of the Teensy-3.6 to the pin headers on the main PCB. The order is straight through as shown in the picture below.

You need:

5 7cm female/female wires

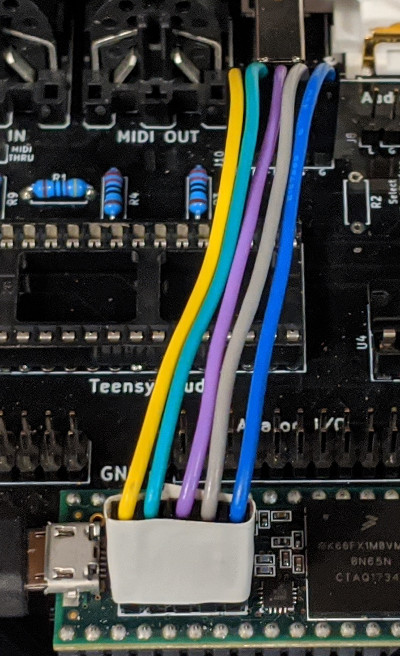
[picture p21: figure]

Insert the Audio Shield

Note the direction in which the Audio Shield must be inserted: If the main PCB is aligned like in the picture below, the SD card slot must point to the right.

You need:

Teensy audio card (not included in the kit)

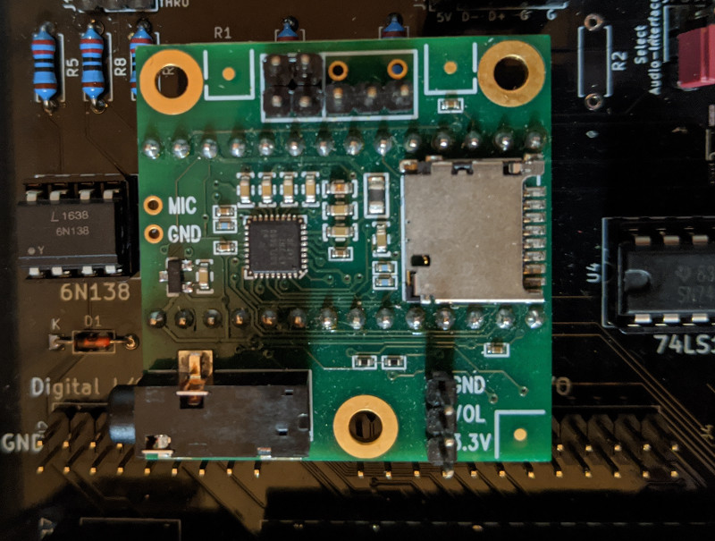
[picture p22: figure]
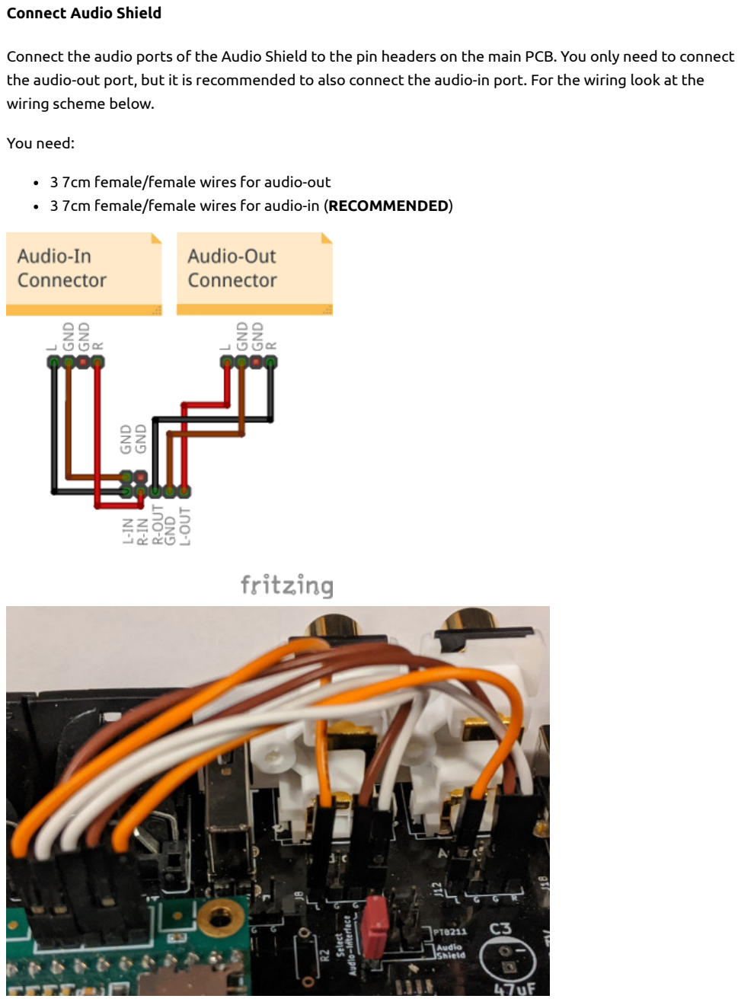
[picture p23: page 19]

Connect Audio Shield

Connect the audio ports of the Audio Shield to the pin headers on the main PCB. You only need to connect the audio-out port, but it is recommended to also connect the audio-in port. For the wiring look at the wiring scheme below.

You need:

3 7cm female/female wires for audio-out
3 7cm female/female wires for audio-in (RECOMMENDED)

Prepare and insert SD card (OPTIONAL: only needed for using TMA with MicroDexed)

Format the SD card as FAT32 and copy the contents of the directory addon from the MicroDexed directory to the SD card. You can also install your own SYSEX files (or load them directly onto the MicroDexed later). It is important to keep the directory structure: For each bank there is a directory with the bank number as name.

The SD card can be inserted into the Teensy or the audio card.

You need:

SD card (not included in the kit)

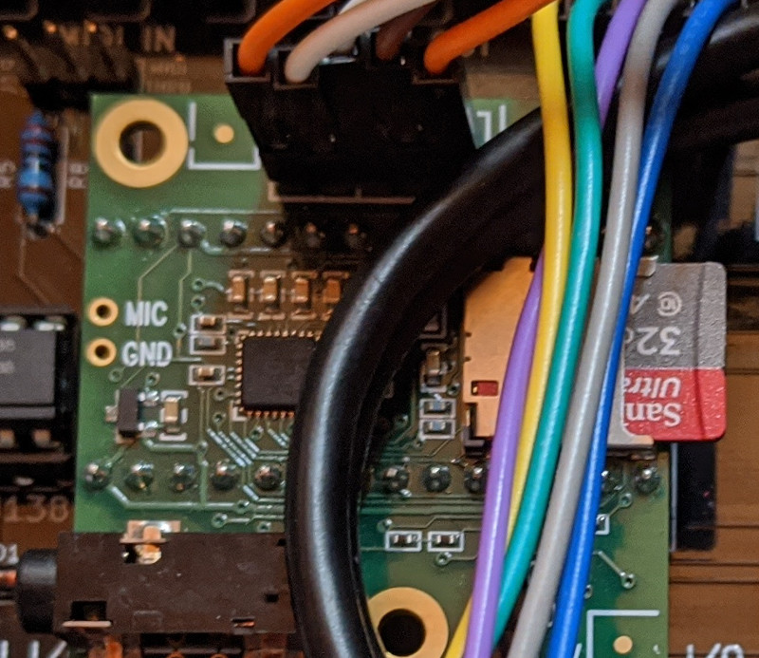
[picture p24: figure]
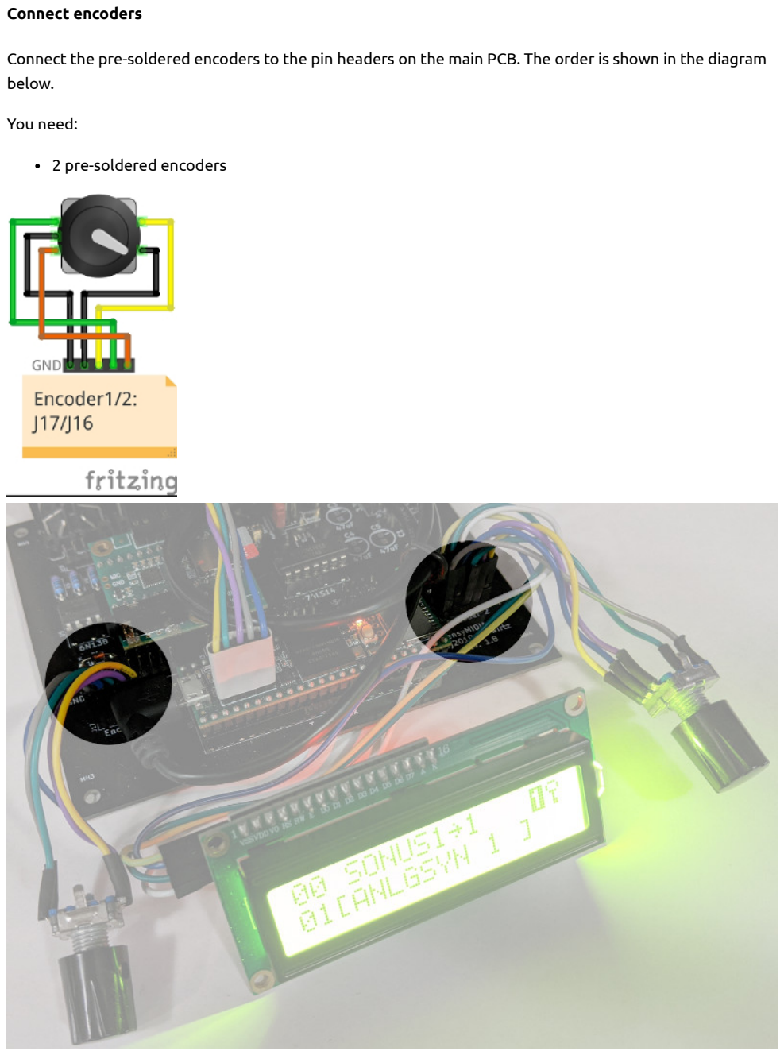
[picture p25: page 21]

Connect encoders

Connect the pre-soldered encoders to the pin headers on the main PCB. The order is shown in the diagram below.

You need:

2 pre-soldered encoders

Setting jumpers

The jumpers are needed to decide which kind of I2S sound chip you want to use and to enable the I2C pullup resistors. To enable them close JP4 and JP5. Then set JP3 to the down position (as seen in the picture below) and leave JP1 and JP2 open.

You need:

3 jumpers

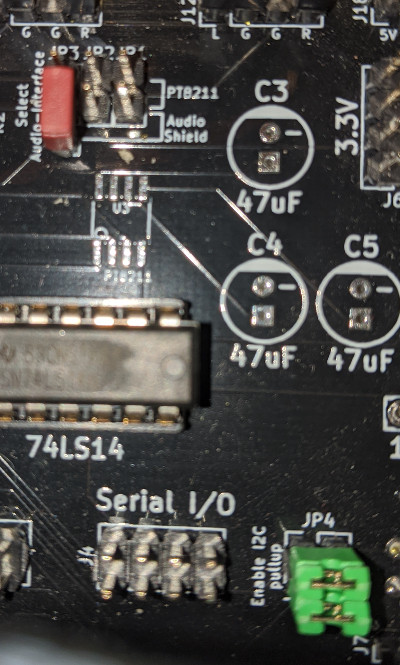
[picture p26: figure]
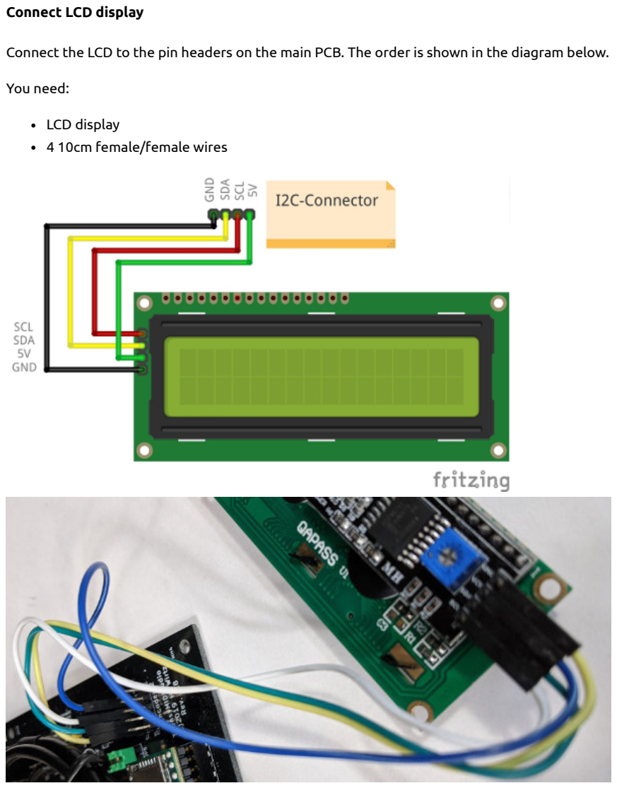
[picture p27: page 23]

Connect LCD display

Connect the LCD to the pin headers on the main PCB. The order is shown in the diagram below.

You need:

LCD display
4 10cm female/female wires

Test

Now you are ready for the first test. But before, please check again the following:

orientation of the ICs
orientation of the Teensy
orientation of the Audio Shield OPTIONAL: SD card is inserted

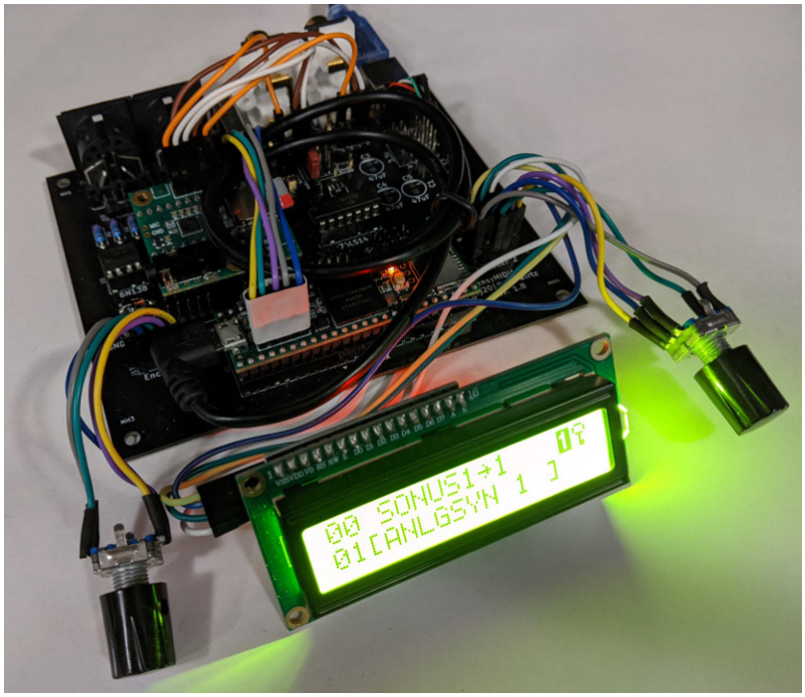
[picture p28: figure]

Now you can try to power up your kit. If everything works, the display should show a short text during the boot process. After that you you should see the bank/voice selection. Now you can play with your connected MIDI keyboard and change sounds/banks with the encoder. For more information on how to use it please read the user-manual.

Trouble-shooting

Problem: Nothing is visible on the LCD

This can happen if the contrast of the LCD display is not set correctly. To adjust it you can (carefully) adjust the contrast with a small screwdriver using the blue potentiometer on the back of the LCD display while power is connected.

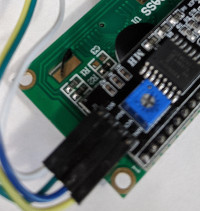
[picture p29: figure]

Problem: The screen hangs on the boot message!

This may be due to problems with the SD card? The synth will only work if the SD card works correctly. If the SD card is not recognized, the system will stop. Try to format it again as FAT32 and copy the preset data or try another SD card.

Problem: The encoders are reversed!

The lines on the encoder (on the three-pin side, the lines on the right and left) have been connected to the headers in reverse order. Exchange them crosswise on the main board.

Problem: The encoder buttons don't work!

Check if the two wires from the encoder (from the two pin side) are connected to the correct header on the main board.

It is also possible that the potentiometer knobs are mounted too close to the encoder. Loosen the screw in the potentiometer knob and push the knob a bit further away from the case. You can also remove it first and try to push the buttons without the knobs.

Problem: There is no sound!

First check your MIDI wiring.
MicroDexed
Are you getting signals? The LCD should show a note symbol or a box symbol under the inverse 1 when you press a key. If not, no MIDI signals are detected and no sound is generated.
Did you reset the EEPROM? You may need to reset the EEPROM after each time you flashed the firmware.
Is the volume high enough? Turn the volume encoder (left) so that the display shows you a higher value (maximum 100).
Has the SD card been recognized? You can only hear the sound if the SD card has been recognized correctly. If not, format it again as FAT32 and copy the data or try another SD card. Check the output level.

## Contact

Email: info@parasitstudio.de

Web: https://www.parasitstudio.de

## Appendix

Circuit diagram

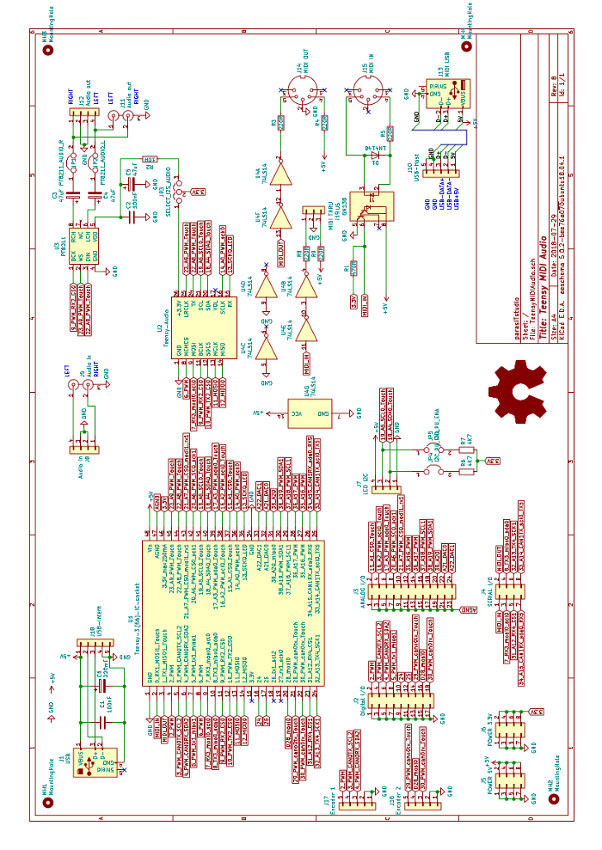
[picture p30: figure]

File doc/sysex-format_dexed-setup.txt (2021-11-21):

THIS DOCUMENT HAS TO BE FIXED!!!!

EXTENDED SYSEX FORMAT FOR MICRODEXED
====================================

SYSEX Message Controller-Set
----------------------------

     11110000  F0   Status byte - start sysex
     0iiiiiii  67   ID # (i=103; unofficial SYSEX-ID for MicroDexed)
     0fffffff  **   format number (f=66 MicroDexed voice config)
     0ddddddd  **   data byte 1 setup config

        |       |       |

     0ddddddd  **   data byte 35
     0eeeeeee  **   checksum (masked 2's complement of sum of 155 bytes)
     11110111  F7   Status - end sysex

Data Structure: MicroDexed Setup Dump
-------------------------------------
 Number    Parameter                     Value Range
---------  ---------                     -----------
01         DEXED LOWEST NOTE           21-108
02         DEXED HIGHEST NOTE          21-108
03         DEXED REVERB SEND           0-100
04         DEXED CHORUS SEND           0-100
05         DEXED DELAY SEND            0-100
06         DEXED FILTER-CUTOFF         0-100
07         DEXED FILTER-RESONANCE      0-100
08         DEXED TRANSPOSE             0-48
09         DEXED TUNE                  0-100
10         DEXED SOUND INTENSITY       0-100
11         DEXED PANORAMA	         0-40    (20 is middle)
12         DEXED POLYPHONY             0-32    (depends on CPU and FX)
13         DEXED VELOCITY LEVEL        100-127
14         DEXED ENGINE                0-2     1=Modern, 2=Mark1, 2=OPL
15         DEXED MONO/POLY MODE CHANGE 0-1     O=POLY
16         DEXED NOTE REFRESH MODE     0-2
17         DEXED PITCH BEND RANGE      0-12
18         DEXED  "     "   STEP       0-12
19         DEXED MOD WHEEL RANGE       0-99
20         DEXED  "    "   ASSIGN      0-7     b0: pitch,  b1:amp, b2: EG bias
21         DEXED  "    "   MODE        0-2     1=linear, 2=reverse, 3=direct
22         DEXED FOOT CONTROL RANGE    0-99
23         DEXED  "     "     ASSIGN   0-7           "
24         DEXED  "     "     MODE     0-2     1=linear, 2=reverse, 3=direct
25         DEXED BREATH CONT RANGE     0-99
26         DEXED   "     "   ASSIGN    0-7           "
27         DEXED   "     "   MODE      0-2     1=linear, 2=reverse, 3=direct
28         DEXED AFTERTOUCH RANGE      0-99
29         DEXED     "      ASSIGN     0-7           "
30         DEXED     "      MODE       0-2     1=linear, 2=reverse, 3=direct
31         DEXED PORTAMENTO MODE       0-1     0=RETAIN 1=FOLLOW
32         DEXED      "     GLISS      0-1
33         DEXED      "     TIME       0-99
34         DEXED OP_ENABLE             0-31
35         DEXED MIDI-CHANNEL          0-16    0=OMNI

---------
 Number    Parameter                     Value Range
---------  ---------                     -----------
 0         GLOBAL STERO/MONO             0-3  (0=stereo, 1=mono, 2=mono-r, 3=mono-l)
 1         GLOBAL REVERB-ROOMSIZE        0-100
 2         GLOBAL REVERB-DAMPING         0-100
 3         GLOBAL REVERB-LEVEL           0-100
 4         GLOBAL CHORUS-FREQUENCY       0-100 (multiplied by 1/10 Hz)
 5         GLOBAL CHORUS-WAVEFORM        0-1   (0=triangle, 1=sine)
 6         GLOBAL CHORUS-DEPTH           0-100
 7         GLOBAL CHORUS-LEVEL           0-100
 8         GLOBAL DELAY-TIME             0-50  (multiplied by 10ms)
 9         GLOBAL DELAY-FEEDBACK         0-100
10         GLOBAL DELAY-LEVEL            0-100

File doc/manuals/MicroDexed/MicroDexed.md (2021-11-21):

---
fontfamily: dejavu
fontsize: 16pt
geometry: a4paper,margin=2cm
---



written by Holger Wirtz and Thierry Pottier

Version 1.1 (July 2020)

# What is MicroDexed?

MicroDexed is a FM-Software-Synthesizer with six operators and much additional features.
It is written in C/C++ for the microcontroller Teensy-3.6/4.x. The sound generation (msfa)
from the free VST-plugin Dexed was used and a user interface was created using two encoders
and an LCD display.

For the original Dexed/msfa software take a look at [Dexed on Github](https://github.com/asb2m10/dexed) and
[Music Synthesizer for Android on Github](https://github.com/google/music-synthesizer-for-android).

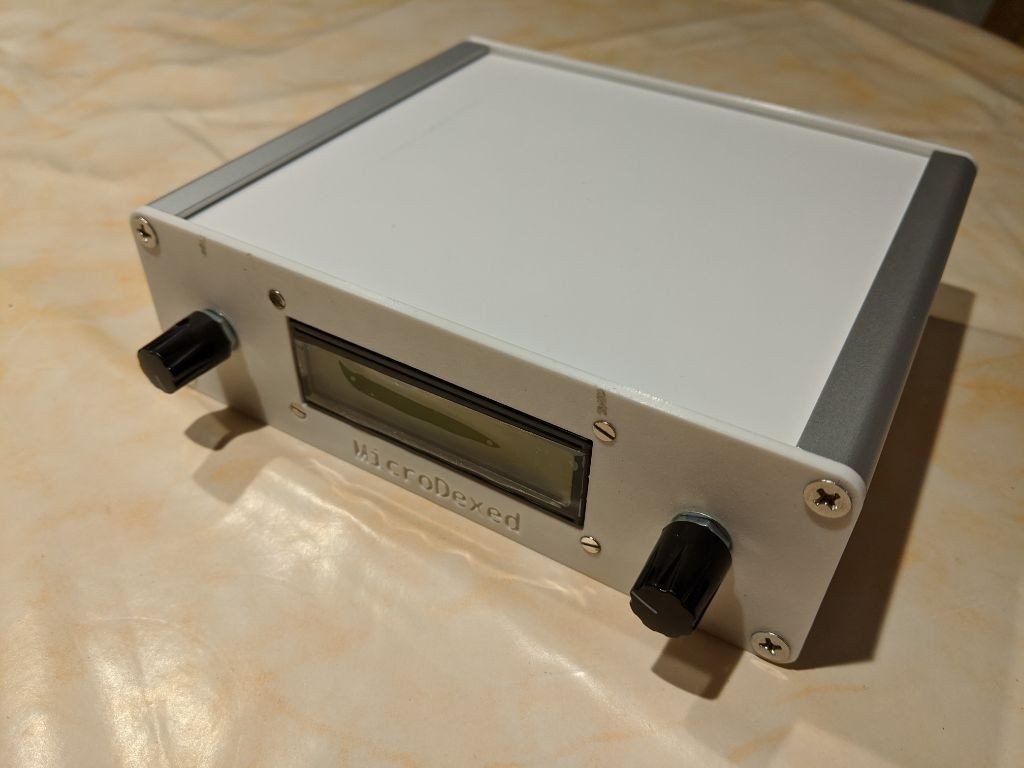
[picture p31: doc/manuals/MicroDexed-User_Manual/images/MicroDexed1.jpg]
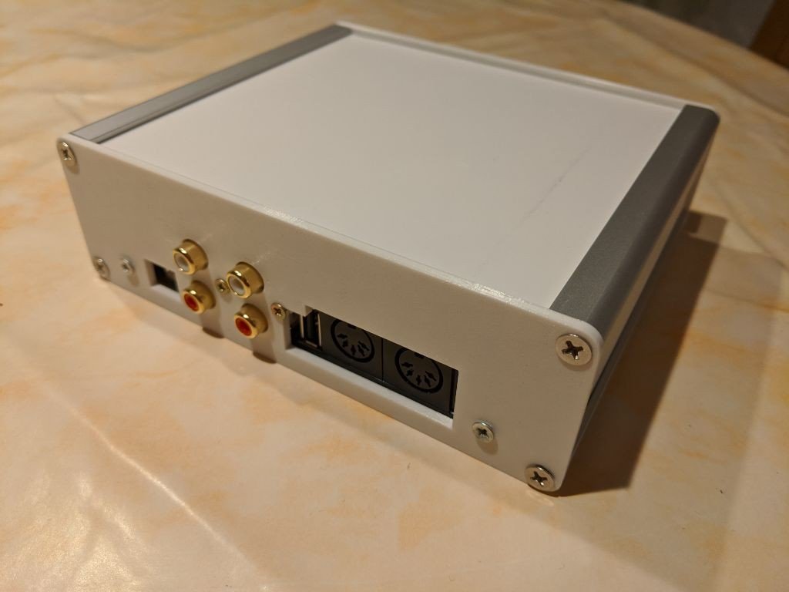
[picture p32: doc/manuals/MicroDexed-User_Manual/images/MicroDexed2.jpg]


## Features

* Compatible to a legendary FM synth with six operators from a famous Japanese manufacturer
* MIDI interface:
	* DIN IN/OUT with software THRU (can be disabled, optional hardware THRU possible)
	* USB-Slave (for connecting to a PC)
	* USB-Master (for connecting keyboards)
* Audio interface:
	* RCA stereo IN/OUT with audio THRU (daisy-chain your sound generators(adds a little bit of noise))
* Onboard effects:
	* Chorus (mono)
	* Delay (mono, up to 500ms, with feedback)
	* Low-pass filter with resonance
	* Reverb (stereo)
	* Resonant low-pass filter 
* Mono sound engine with panorama controller before reverb
* Up to 20 voices of polyphony
* Up to 100 banks of 32 voices can be stored on an SD card
* MIDI SYSEX compatible
	* Sounds can be edited with external editors like...
		* [EdiSyn](https://github.com/eclab/edisyn)
		* [Dexed-VST](https://asb2m10.github.io/dexed/)
		* [DX7 by Vstforx](https://dx7.vstforx.de/)
		* [Synthmata](https://synthmata.com/volca-fm/)
		* [KI generated DX banks](https://www.thisdx7cartdoesnotexist.com/)
	* Sending of Voice/Bank MIDI-SYSEX dumps
	* Receiving of Voice/Bank MIDI-SYSEX dumps
	* Voice-Parameter change via MIDI-SYSEX
	* Flexible MIDI controller settings with additional features
	* Modwheel, Pitchbend, Portamento, Breath-Controller, Aftertouch, Foot-Controller
	* Additional modes for most controllers (linear, inverse, direct)
	* Controller parameter change via MIDI-SYSEX
	* Additional MIDI-CCs
		* Bank select
		* Preset select
		* Volume
		* Panorama
		* Filter resonance
		* Filter cutoff
		* Delay time
		* Delay feedback
		* Delay volume
* Storage of voice presets, effect presets and combinations of both as "performance" on SD card
* Transpose, fine-tune, mono-mode
* Note refresh options: normal or retriggered
* Velocity level adaption 
* Three sound engines:
	* Modern : this is the original 24-bit music-synthesizer-for-android implementation.
	* Mark I : Based on the OPL Series but at a higher resolution (LUT are 10-bits). The target of this engine is to be closest to the real DX7.
	* OPL Series : this is an experimental implementation of the reverse-engineered OPL family chips, 8-bit. Keep in mind that the envelopes still need tuning.
* Open-Source (https://codeberg.org/dcoredump/MicroDexed)

## Manuals

A manual how you can build your own MicroDexed can be found here: [https://codeberg.org/dcoredump/MicroDexed/src/branch/master/doc/manuals/Build-Manual.pdf](https://codeberg.org/dcoredump/MicroDexed/src/branch/master/doc/manuals/Build-Manual.pdf)

A user manual can be found at: [https://codeberg.org/dcoredump/MicroDexed/src/branch/master/doc/manuals/MicroDexed-User_Manual/MicroDexed-User_Manual.pdf](https://codeberg.org/dcoredump/MicroDexed/src/branch/master/doc/manuals/MicroDexed-User_Manual/MicroDexed-User_Manual.pdf)

## License
MicroDexed is licensed under the GPL v3. The msfa component (acronym for music synthesizer for android, see https://github.com/google/music-synthesizer-for-android) stays under the Apache 2.0 license to be able to collaborate between projects.

## Credits & thanks

* Dexed engine by Pascal Gauthier (asb2m10)
* DX Synth engine (as part of Dexed): Raph Levien and the msfa team
* PPPlay : Great OPL3 implementation, with documented code :D
* Thierry Pottier: for extreme testing, discussing about different options, images and many good suggestions for UI handling
* Lars Pelz: Testing and documentation

MicroDexed

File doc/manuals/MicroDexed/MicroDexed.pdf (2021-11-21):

MicroDexed.md | 30.7.2020

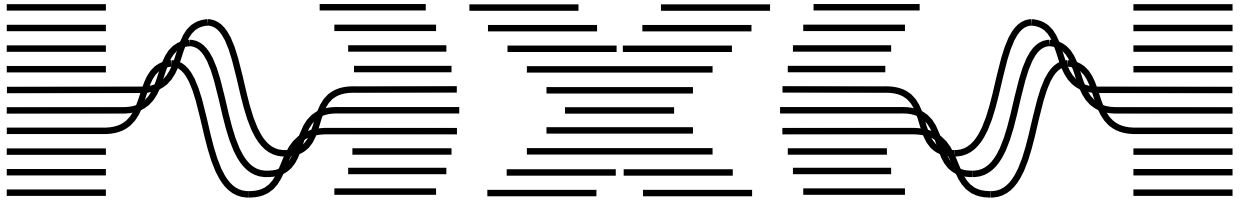
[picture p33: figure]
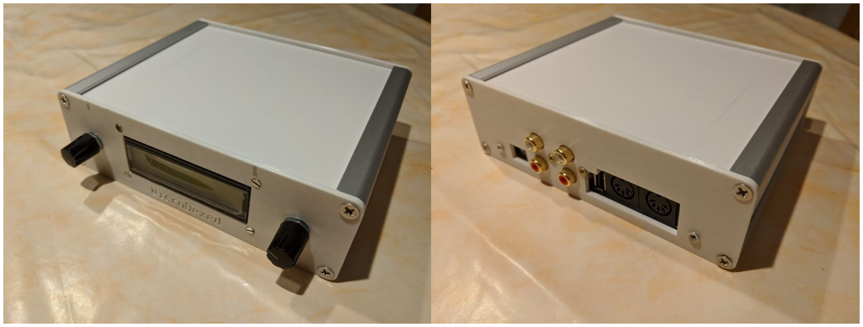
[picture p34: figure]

/

written by Holger Wirtz and Thierry Pottier

Version 1.1 (July 2020)

# What is MicroDexed?

MicroDexed is a FM-Software-Synthesizer with six operators and much additional features. It is written in C/C++ for the microcontroller Teensy-3.6/4.x. The sound generation (msfa) from the free VST-plugin Dexed was used and a user interface was created using two encoders and an LCD display.

For the original Dexed/msfa software take a look at Dexed on Github (https://github.com/asb2m10/dexed) and Music Synthesizer for Android on Github. (https://github.com/google/music-synthesizer-for-android)

## Features

Compatible to a legendary FM synth with six operators from a famous Japanese manufacturer MIDI interface:
DIN IN/OUT with software THRU (can be disabled, optional hardware THRU possible) USB-Slave (for connecting to a PC)
USB-Master (for connecting keyboards)
Audio interface:
RCA stereo IN/OUT with audio THRU (daisy-chain your sound generators(adds a little bit of noise))

Onboard effects:
Chorus (mono)
Delay (mono, up to 500ms, with feedback) Low-pass filter with resonance
Reverb (stereo)
Resonant low-pass filter
Mono sound engine with panorama controller before reverb Up to 20 voices of polyphony
Up to 100 banks of 32 voices can be stored on an SD card MIDI SYSEX compatible
Sounds can be edited with external editors like... EdiSyn (https://github.com/eclab/edisyn)
Dexed-VST (https://asb2m10.github.io/dexed/)
DX7 by Vstforx (https://dx7.vstforx.de/)
Synthmata (https://synthmata.com/volca-fm/)
KI generated DX banks (https://www.thisdx7cartdoesnotexist.com/)
Sending of Voice/Bank MIDI-SYSEX dumps
Receiving of Voice/Bank MIDI-SYSEX dumps
Voice-Parameter change via MIDI-SYSEX
Flexible MIDI controller settings with additional features
Modwheel, Pitchbend, Portamento, Breath-Controller, Aftertouch, Foot-Controller Additional modes for most controllers (linear, inverse, direct)
Controller parameter change via MIDI-SYSEX
Additional MIDI-CCs
Bank select
Preset select
Volume
Panorama
Filter resonance
Filter cutoff
Delay time
Delay feedback
Delay volume
Storage of voice presets, effect presets and combinations of both as "performance" on SD card Transpose, fine-tune, mono-mode
Note refresh options: normal or retriggered
Velocity level adaption
Three sound engines:
Modern : this is the original 24-bit music-synthesizer-for-android implementation.
Mark I : Based on the OPL Series but at a higher resolution (LUT are 10-bits). The target of this engine is to be closest to the real DX7.
OPL Series : this is an experimental implementation of the reverse-engineered OPL family chips, 8-bit. Keep in mind that the envelopes still need tuning.
Open-Source (https://codeberg.org/dcoredump/MicroDexed)

## Manuals

A manual how you can build your own MicroDexed can be found here: https://codeberg.org/dcoredump/MicroDexed/src/branch/master/doc/manuals/Build-Manual.pdf

A user manual can be found at: https://codeberg.org/dcoredump/MicroDexed/src/branch/master/doc/manuals/MicroDexed-User_Manual/MicroDexed-User_Manual.pdf (https://codeberg.org/dcoredump/MicroDexed/src/branch/master/doc/manuals/MicroDexed-User_Manual/MicroDexed-User_Manual.pdf)

## License

MicroDexed is licensed under the GPL v3. The msfa component (acronym for music synthesizer for android, see https://github.com/google/music-synthesizer-for-android) stays under the Apache 2.0 license to be able to collaborate between projects.

## Credits & thanks

Dexed engine by Pascal Gauthier (asb2m10)
DX Synth engine (as part of Dexed): Raph Levien and the msfa team
PPPlay : Great OPL3 implementation, with documented code
Thierry Pottier: for extreme testing, discussing about different options, images and many good suggestions for UI handling
Lars Pelz: Testing and documentation

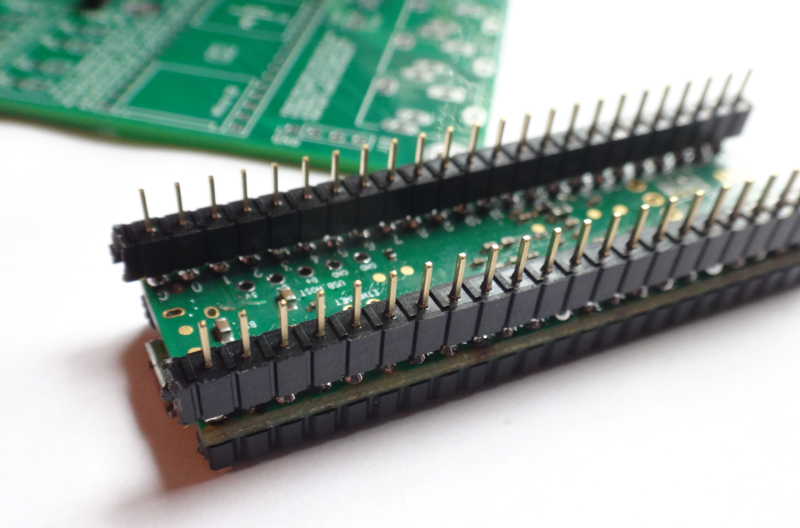
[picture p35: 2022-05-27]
doc/Build_InstructionsV2/teensywithheaderandsockets.png

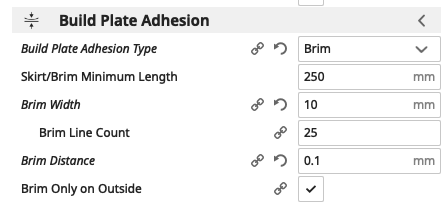
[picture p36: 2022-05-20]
doc/Build_InstructionsV2/slicer2.png

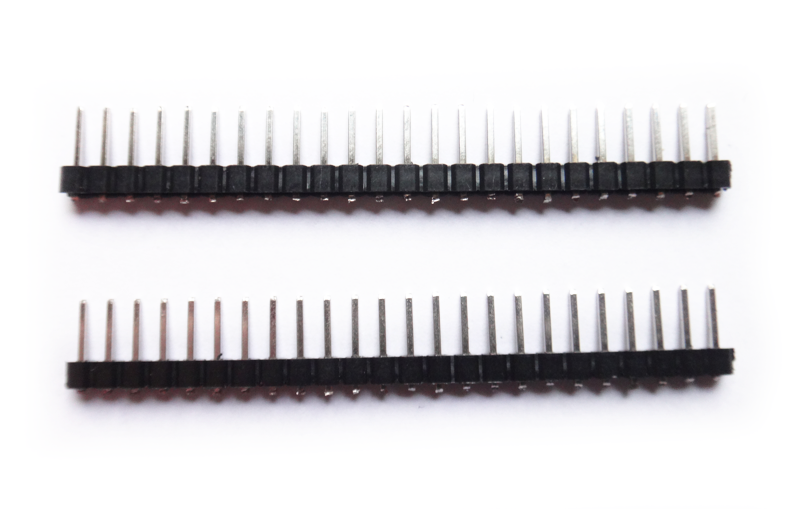
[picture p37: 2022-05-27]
doc/Build_InstructionsV2/cut-pins-teensy.png

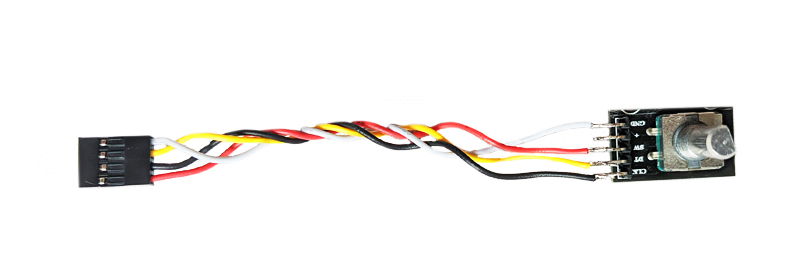
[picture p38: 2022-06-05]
doc/Build_InstructionsV2/encoder.jpg

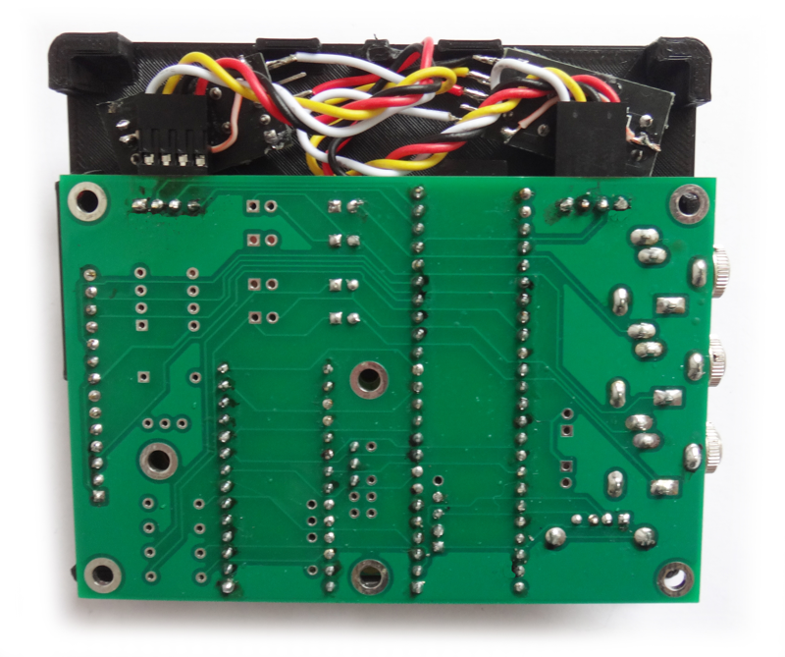
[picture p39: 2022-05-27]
doc/Build_InstructionsV2/lidwithpcb.png

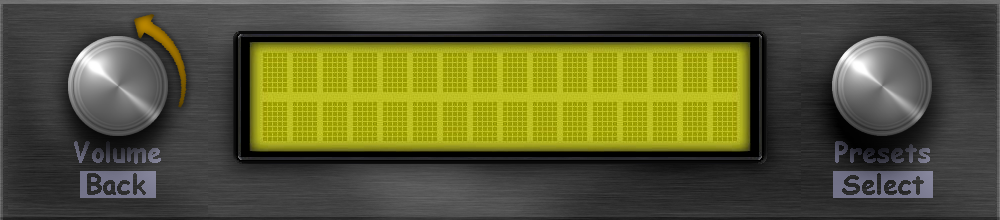
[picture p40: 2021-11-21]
doc/images/manual-images/Volume_Up.png

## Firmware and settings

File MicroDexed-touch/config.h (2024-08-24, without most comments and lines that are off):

#pragma once
#include <Arduino.h>
#include "midinotes.h"
#include "teensy_board_detection.h"
#define DBG_LOG(s)
#include "version.h"
#define MIDI_DEVICE_DIN Serial1
#define MIDI_DEVICE_USB 1
#define MIDI_DEVICE_USB_HOST
#define I2S_AUDIO_ONLY // for PCM5102 or other I2S DACs
#define DEFAULT_MIDI_CHANNEL MIDI_CHANNEL_OMNI
#define SYSEXBANK_DEFAULT 0
#define SYSEXSOUND_DEFAULT 0
#define SERIAL_SPEED 230400
#define SHOW_CPU_LOAD_MSEC 5000
#if !defined(COMPILE_FOR_PROGMEM) && !defined(COMPILE_FOR_FLASH) && !defined(COMPILE_FOR_SDCARD) && !defined(COMPILE_FOR_PSRAM)
#define COMPILE_FOR_PROGMEM // default
#endif
#ifndef CAPACITIVE_TOUCH_DISPLAY // TFT with Capacitive Touchscreen, currently for testing purposes only
#define GENERIC_DISPLAY // generic/noname ILI941 TFT + XPT2046 Touchscreen (default)
#endif
#define NUM_DEXED 2 // 1 or 2 - nothing else!
#define DEFAULT_DEXED_MIDI_CHANNEL_INST0 1
#define DEFAULT_DEXED_MIDI_CHANNEL_INST1 2
#define NUM_DRUMS 8 // set 0 to disable Drums
#define DEFAULT_DRUM_MIDI_CHANNEL 10
#define NUM_CUSTOM_MIDI_MAPPINGS 18 // Number of Custom Key, CC and Button Mappings
#define NUM_CUSTOM_SAMPLES 20
#define NUM_STATIC_PITCHED_SAMPLES 6
#define NUM_DRUMSET_CONFIG 71 + NUM_CUSTOM_SAMPLES
#define NUM_SEQ_PATTERN 32
#define NUM_SEQ_TRACKS 8
#define SONG_LENGTH 64
#define NUM_CHAINS 32
#define NUM_MULTISAMPLES 2
#define NUM_MULTISAMPLE_ZONES 8
#define DEFAULT_MSP_MIDI_CHANNEL_INST0 7
#define DEFAULT_MSP_MIDI_CHANNEL_INST1 8
#define NUM_EPIANO_VOICES 16
#define DEFAULT_EP_MIDI_CHANNEL 3
#define NUM_MICROSYNTH 2
#define DEFAULT_MICROSYNTH_MIDI_CHANNEL_INST0 4
#define DEFAULT_MICROSYNTH_MIDI_CHANNEL_INST1 5
#define NUM_BRAIDS 8
#define DEFAULT_BRAIDS_MIDI_CHANNEL 6
#define VIRT_KEYB_YPOS 166
#define MOD_DELAY_SAMPLE_BUFFER int32_t(TIME_MS2SAMPLES(15.0)) // 15.0 ms delay buffer.
#define MOD_WAVEFORM WAVEFORM_TRIANGLE                         // WAVEFORM_SINE WAVEFORM_TRIANGLE WAVEFORM_SAWTOOTH WAVEFORM_SAWTOOTH_REVERSE
#define MOD_FILTER_OUTPUT MOD_BUTTERWORTH_FILTER_OUTPUT        // MOD_LINKWITZ_RILEY_FILTER_OUTPUT MOD_BUTTERWORTH_FILTER_OUTPUT MOD_NO_FILTER_OUTPUT
#define MOD_FILTER_CUTOFF_HZ 2000
#define DELAY_MAX_TIME 500  // 0.5s
#define SAMPLE_RATE 44100
#define AUDIO_MEM SAMPLE_RATE *NUM_DEXED *DELAY_MAX_TIME / 128000 + 36 + 14
#define COLOR_BACKGROUND 0x0000
#define COLOR_SYSTEXT 0xFFFF
#define DX_DARKCYAN 0x030D
#define COLOR_INSTR 0x7BBD
#define COLOR_CHORDS 0xE2FA
#define COLOR_ARP 0xFC80
#define COLOR_DRUMS 0xFE4F
#define COLOR_PITCHSMP 0x159A
#define RED 0xD000
#define PINK 0xF81F
#define YELLOW 0xFFEB
#define GREEN 0x07E0
#define MIDDLEGREEN 0x1500
#define DARKGREEN 0x0AE0
#define GREY1 0xC638
#define GREY2 0x52AA
#define GREY3 0x2104
#define GREY4 0x10A2
const char back_text[5] = { 'B', 'A', 'C', 'K' };
const char back_clear[5] = { ' ', ' ', ' ', ' ' };
#define TFT_WIDTH 240
#define TFT_HEIGHT 320
#define DISPLAY_WIDTH 320
#define DISPLAY_HEIGHT 240
#define display_cols 20
#define display_rows 6
#define CHAR_width 12
#define CHAR_height 17
#define CHAR_width_small 6
#define CHAR_height_small 8
#define button_size_x 7
#define button_size_y 4
#define TFT_DC 37
#define TFT_CS 41
#define TFT_RST 24
#define TFT_SCK 27
#define TFT_MISO 39
#define TFT_MOSI 26
#define TFT_TOUCH_IRQ 33
#if defined GENERIC_DISPLAY
#define TFT_TOUCH_CS 38
#endif
#define VOICE_SELECTION_MS 60000
#define BACK_FROM_VOLUME_MS 2000
#define MESSAGE_WAIT_TIME 1000
#define MIDI_DECAY_TIMER 50
const int FlashChipSelect = 6; // digital pin for flash chip CS pin
#define NUM_ENCODER 2
#define ENC_L_PIN_A 32
#define ENC_L_PIN_B 31
#define BUT_L_PIN 30
#define ENC_R_PIN_A 28
#define ENC_R_PIN_B 29
#define BUT_R_PIN 25
#define BUT_DEBOUNCE_MS 20
#define LONG_BUTTON_PRESS 500
#define AUTOSTORE_MS 5000
#define DEXED_POOLS 100
#define DEXED_CONFIG_PATH "DEXED"
#define FAV_CONFIG_PATH "FAVCFG"
#define MAX_BANKS 100
#define MAX_VOICES 32     // voices per bank
#define BANK_NAME_LEN 11  // 10 (plus '\0')
#define VOICE_NAME_LEN 12 // 11 (plus '\0')
#define FILENAME_LEN BANK_NAME_LEN + VOICE_NAME_LEN
#define CONFIG_FILENAME_LEN 50
#define DRUM_NAME_LEN 21
#define PERFORMANCE_CONFIG_PATH "PERFORMANCE"
#define SEQUENCER_CONFIG_NAME "sequencer"
#define DRUMS_CONFIG_NAME "drums"
#define DRUMS_MAPPING_NAME "drmmap"
#define PATTERN_CONFIG_NAME "patterns"
#define VELOCITY_CONFIG_NAME "velocity"
#define CHAIN_CONFIG_NAME "chain"
#define TRANSPOSE_CONFIG_NAME "transp"
#define SONG_CONFIG_NAME "song"
#define FX_CONFIG_NAME "fx"
#define VOICE_CONFIG_NAME "voice"
#define SYS_CONFIG_NAME "sys"
#define EPIANO_CONFIG_NAME "epiano"
#define MICROSYNTH_CONFIG_NAME "msynth"
#define MULTISAMPLE_PRESETS_CONFIG_NAME "msp_presets"
#define BRAIDS_CONFIG_NAME "braids"
#define MULTIBAND_CONFIG_NAME "multiband"
#define SIDECHAIN_CONFIG_NAME "sc"
#define LIVESEQUENCER_CONFIG_NAME "liveseq"
#define SAMPLES_CONFIG_NAME "samples"
#define MAX_PERF_MOD 30
#define MAX_FILES 150
#define MAX_FLASH_FILENAME_LEN 64
#define PCM5102_MUTE_PIN 34 // hardware pin for PCM5102 XSMT soft mute function
#define AUDIO_DEVICE_USB
#define MAX_DEXED 2 // No! - even don't think about increasing this number! IT _WILL_ PRODUCE MASSIVE PROBLEMS!
#define CONTROL_RATE_MS 50
#define MICROSYNTH_CONTROL_RATE_MS 30
#define BRAIDS_CONTROL_RATE_MS 30
#define SAVE_SYS_MS 5000
#define VOL_MAX_FLOAT 0.98
#define ALL_STATIC_DELAY_INSTR_OUT 8  // static delay sends
#ifdef TEENSY4
#define MAX_NOTES 32
#define MIDI_DECAY_LEVEL_TIME 500
#endif
#define USE_TEENSY_DSP 1
#define TIME_MS2SAMPLES(x) floor(uint32_t(x) * AUDIO_SAMPLE_RATE / 1000) * sizeof(int16_t)
#define SAMPLES2TIME_MS(x) float(uint32_t(x) * 1000 / AUDIO_SAMPLE_RATE * sizeof(int16_t)
#define XSTR(x) STR(x)
#define STR(x) #x
#define MOD_NO_FILTER_OUTPUT 0
#define MOD_BUTTERWORTH_FILTER_OUTPUT 1
#define MOD_LINKWITZ_RILEY_FILTER_OUTPUT 2
#if defined(TEENSY_DAC_SYMMETRIC)
#define MONO_MIN 1
#define MONO_MAX 1
#define MONO_DEFAULT 1
#else
#define MONO_MIN 0
#define MONO_MAX 3
#define MONO_DEFAULT 0
#endif
#define MIDI_CONTROLLER_MODE_MAX 2
#define VOLUME_MIN 0
#define VOLUME_MAX 100
#define VOLUME_DEFAULT 80
#define PANORAMA_MIN 0
#define PANORAMA_MAX 40
#define PANORAMA_DEFAULT 20
#define MIDI_CHANNEL_MIN MIDI_CHANNEL_OMNI
#define MIDI_CHANNEL_MAX 16
#define MIDI_CHANNEL_DEFAULT MIDI_CHANNEL_OMNI
#define INSTANCE_LOWEST_NOTE_MIN 21
#define INSTANCE_LOWEST_NOTE_MAX 108
#define INSTANCE_LOWEST_NOTE_DEFAULT 21
#define INSTANCE_HIGHEST_NOTE_MIN 21
#define INSTANCE_HIGHEST_NOTE_MAX 108
#define INSTANCE_HIGHEST_NOTE_DEFAULT 108
#define CHORUS_FREQUENCY_MIN 0
#define CHORUS_FREQUENCY_MAX 100
#define CHORUS_FREQUENCY_DEFAULT 0
#define CHORUS_WAVEFORM_MIN 0
#define CHORUS_WAVEFORM_MAX 1
#define CHORUS_WAVEFORM_DEFAULT 0
#define CHORUS_DEPTH_MIN 0
#define CHORUS_DEPTH_MAX 100
#define CHORUS_DEPTH_DEFAULT 0
#define CHORUS_LEVEL_MIN 0
#define CHORUS_LEVEL_MAX 100
#define CHORUS_LEVEL_DEFAULT 0
#define DELAY_TIME_MIN 0
#define DELAY_TIME_MAX DELAY_MAX_TIME / 10
#define DELAY_TIME_DEFAULT 0
#define DELAY_FEEDBACK_MIN 0
#define DELAY_FEEDBACK_MAX 100
#define DELAY_FEEDBACK_DEFAULT 0
#define DELAY_LEVEL_MIN 0
#define DELAY_LEVEL_MAX 100
#define DELAY_LEVEL_DEFAULT 0
#define DELAY_LEVEL_GLOBAL_DEFAULT 100
#define DELAY_SYNC_MIN 0
#define DELAY_SYNC_MAX 9
#define DELAY_SYNC_DEFAULT 0
#define REVERB_ROOMSIZE_MIN 0
#define REVERB_ROOMSIZE_MAX 100
#define REVERB_ROOMSIZE_DEFAULT 0
#define REVERB_DAMPING_MIN 0
#define REVERB_DAMPING_MAX 100
#define REVERB_DAMPING_DEFAULT 0
#define REVERB_LOWPASS_MIN 0
#define REVERB_LOWPASS_MAX 100
#define REVERB_LOWPASS_DEFAULT 0
#define REVERB_LODAMP_MIN 0
#define REVERB_LODAMP_MAX 100
#define REVERB_LODAMP_DEFAULT 0
#define REVERB_HIDAMP_MIN 0
#define REVERB_HIDAMP_MAX 100
#define REVERB_HIDAMP_DEFAULT 0
#define REVERB_DIFFUSION_MIN 0
#define REVERB_DIFFUSION_MAX 100
#define REVERB_DIFFUSION_DEFAULT 0
#define REVERB_LEVEL_MIN 0
#define REVERB_LEVEL_MAX 100
#define REVERB_LEVEL_DEFAULT 0
#define REVERB_SEND_MIN 0
#define REVERB_SEND_MAX 100
#define REVERB_SEND_DEFAULT 0
#define FILTER_CUTOFF_MIN 0
#define FILTER_CUTOFF_MAX 100
#define FILTER_CUTOFF_DEFAULT 0
#define FILTER_RESONANCE_MIN 0
#define FILTER_RESONANCE_MAX 100
#define FILTER_RESONANCE_DEFAULT 0
#define TRANSPOSE_MIN 0
#define TRANSPOSE_MAX 48
#define TRANSPOSE_DEFAULT 12
#define TUNE_MIN 1
#define TUNE_MAX 199
#define TUNE_DEFAULT 100
#define SOUND_INTENSITY_MIN 0
#define SOUND_INTENSITY_MAX 100
#define SOUND_INTENSITY_DEFAULT 100
#define POLYPHONY_MIN 0
#define POLYPHONY_MAX MAX_NOTES
#define POLYPHONY_DEFAULT MAX_NOTES / NUM_DEXED
#define MONOPOLY_MIN 0
#define MONOPOLY_MAX 1
#define MONOPOLY_DEFAULT 0
#define NOTE_REFRESH_MIN 0
#define NOTE_REFRESH_MAX 1
#define NOTE_REFRESH_DEFAULT 0
#define PB_RANGE_MIN 0
#define PB_RANGE_MAX 12
#define PB_RANGE_DEFAULT 1
#define PB_STEP_MIN 0
#define PB_STEP_MAX 12
#define PB_STEP_DEFAULT 0
#define MW_RANGE_MIN 0
#define MW_RANGE_MAX 99
#define MW_RANGE_DEFAULT 50
#define MW_ASSIGN_MIN 0
#define MW_ASSIGN_MAX 7
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

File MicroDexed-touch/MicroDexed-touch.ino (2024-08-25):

/*
   MicroDexed-touch

   MicroDexed is a port of the Dexed sound engine
   Dexed ist heavily based on https://github.com/google/music-synthesizer-for-android

   (c)2018-2021 H. Wirtz <wirtz@parasitstudio.de>
   (c)2021      H. Wirtz <wirtz@parasitstudio.de>, M. Koslowski <positionhigh@gmx.de>

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
   You should have received a copy of the GNU General Public License
   along with this program; if not, write to the Free Software Foundation,
   Inc., 51 Franklin Street, Fifth Floor, Boston, MA 02110-1301  USA
*/

#include <limits.h>
#include "config.h"
#include "scope.h"
#include <Audio.h>
#include <Wire.h>
#include <MIDI.h>
#include <SD.h>
#include <SPI.h>
#include <flashloader.h>

#include "ILI9341_t3n.h"

#if defined GENERIC_DISPLAY
#include "XPT2046_Touchscreen.h"
#endif

#ifdef CAPACITIVE_TOUCH_DISPLAY
#include "Adafruit_FT6206.h"
#endif

#if defined(COMPILE_FOR_PROGMEM) || defined(COMPILE_FOR_PSRAM)
#include <TeensyVariablePlayback.h>
#endif

#ifdef COMPILE_FOR_SDCARD
#include <TeensyVariablePlayback.h>
#endif

#ifdef COMPILE_FOR_FLASH
#include "TeensyVariablePlaybackFlash.h"
#endif

// #ifdef COMPILE_FOR_FLASH
// SerialFlashChip         myfs;
// #endif

extern "C" uint8_t external_psram_size;
uint32_t psram_free_bytes = 0;

#ifdef PSRAM
#include "effect_delay_ext8.h"
#endif

#include <synth_braids.h>
// Allocate the delay lines for left and right channels
short braids_l_delayline[BRAIDS_FLANGE_DELAY_LENGTH];
short braids_r_delayline[BRAIDS_FLANGE_DELAY_LENGTH];
int braids_flanger_idx = BRAIDS_FLANGE_DELAY_LENGTH / 4;
int braids_flanger_depth = BRAIDS_FLANGE_DELAY_LENGTH / 4;
double braids_flanger_freq = .5;

#include <TeensyTimerTool.h>
using namespace TeensyTimerTool;

#include "microsynth.h"
#include "braids.h"

#include "effect_dynamics.h"

#include "midi_devices.hpp"
#include "synth_dexed.h"
#include "dexed_sd.h"
#include "effect_modulated_delay.h"
#include "effect_stereo_mono.h"
#include "effect_mono_stereo.h"
#include "effect_platervbstereo.h"
#include "template_mixer.hpp"
#include "UI.hpp"
#include "drums.h"
//#include "drumset.h"
#include "synth_mda_epiano.h"
#include "effect_stereo_panorama.h"

#include "livesequencer.h"
#include <vector>

elapsedMillis midi_start_delay;

uint8_t check_sd_cards(void);
void check_and_create_directories(void);
void show_cpu_and_mem_usage(void);
void initial_values(bool init);

void loadSample(newdigate::flashloader& loader, uint8_t i, const char* path);
void printLoadedSample(const uint8_t i, const char* name);

#ifdef DEBUG
void show_configuration(void);
void show_cpu_and_mem_usage(void);
void show_patch(uint8_t);
void SerialPrintFormatInt3(uint8_t num);
int FreeMem(void);
#endif

bool checkMidiChannelDexed(byte inChannel, uint8_t instance_id);
bool bootup_performance_loading = true;
bool remote_active = false;

ILI9341_t3n display = ILI9341_t3n(TFT_CS, TFT_DC, TFT_RST, TFT_MOSI, TFT_SCK, TFT_MISO);

#if defined GENERIC_DISPLAY 
XPT2046_Touchscreen touch(TFT_TOUCH_CS);
#endif

#ifdef CAPACITIVE_TOUCH_DISPLAY
Adafruit_FT6206 touch = Adafruit_FT6206();
#endif

// Editor operations
int menuhelper_previous_val;
bool menuhelper_redraw = false;
int sub(int A, int B, int min, int max)
{
  if (A != constrain(A - B, min, max))
    menuhelper_redraw = true;
  return constrain(A - B, min, max);
};

int sum(int A, int B, int min, int max)
{
  if (A != constrain(A + B, min, max))
    menuhelper_redraw = true;
  return constrain(A + B, min, max);
};

int (*calc_val[2])(int, int, int, int);

Realtime_Scope scope;

// Audio engines
AudioSynthDexed* MicroDexed[NUM_DEXED];
AudioSynthEPiano ep(NUM_EPIANO_VOICES);
AudioAnalyzePeak ep_peak_r;
AudioAnalyzePeak ep_peak_l;

//bitcrusher
// AudioEffectBitcrusher bitcrusher_r;
// AudioEffectBitcrusher bitcrusher_l;

AudioSynthBraids* synthBraids[NUM_BRAIDS];
AudioMixer<NUM_BRAIDS> braids_mixer;
AudioMixer<4>* braids_mixer_filter[NUM_BRAIDS];
AudioMixer<2> braids_mixer_reverb;
AudioEffectEnvelope* braids_envelope[NUM_BRAIDS];
AudioFilterBiquad* braids_filter[NUM_BRAIDS];
AudioEffectFlange braids_flanger_r;
AudioEffectFlange braids_flanger_l;
AudioEffectStereoPanorama braids_stereo_panorama;
AudioAnalyzePeak braids_peak_r;
AudioAnalyzePeak braids_peak_l;
uint8_t braids_slot;
braids_t braids_osc;
uint16_t braids_filter_state[NUM_BRAIDS];
uint16_t braids_filter_state_last_displayed[NUM_BRAIDS];
extern uint16_t braids_filter_lfo_count[NUM_BRAIDS];
extern bool braids_lfo_direction[NUM_BRAIDS];
extern elapsedMillis braids_control_rate;

AudioSynthWaveform microsynth_waveform[NUM_MICROSYNTH];
AudioSynthNoisePink microsynth_noise[NUM_MICROSYNTH];
AudioEffectEnvelope microsynth_envelope_osc[NUM_MICROSYNTH];
AudioEffectEnvelope microsynth_envelope_noise[NUM_MICROSYNTH];
AudioFilterStateVariable microsynth_filter_osc[NUM_MICROSYNTH];
AudioFilterStateVariable microsynth_filter_noise[NUM_MICROSYNTH];
AudioEffectStereoPanorama microsynth_stereo_panorama_osc[NUM_MICROSYNTH];
AudioEffectStereoPanorama microsynth_stereo_panorama_noise[NUM_MICROSYNTH];
AudioMixer<2> microsynth_mixer_r[NUM_MICROSYNTH];
AudioMixer<2> microsynth_mixer_l[NUM_MICROSYNTH];
AudioMixer<2> microsynth_main_mixer_r;
AudioMixer<2> microsynth_main_mixer_l;
AudioMixer<4> microsynth_mixer_filter_osc[NUM_MICROSYNTH];
AudioMixer<4> microsynth_mixer_filter_noise[NUM_MICROSYNTH];
AudioMixer<2> microsynth_mixer_reverb;
AudioAnalyzePeak microsynth_peak_osc_0;
AudioAnalyzePeak microsynth_peak_osc_1;
AudioAnalyzePeak microsynth_peak_noise_0;
AudioAnalyzePeak microsynth_peak_noise_1;
extern elapsedMillis microsynth_delay_timer[2];

AudioSynthWaveform* chorus_modulator[NUM_DEXED];

AudioEffectModulatedDelay* dexed_chorus[NUM_DEXED];

AudioMixer<8 + NUM_DRUMS>* global_delay_in_mixer[NUM_DEXED];
AudioMixer<2>* delay_fb_mixer[NUM_DEXED];

AudioFilterStateVariable global_delay_filter[NUM_DEXED];
AudioMixer<4> global_delay_filter_mixer[NUM_DEXED];

#ifdef PSRAM
AudioEffectDelayExternal8* delay_fx[NUM_DEXED];
#else
AudioEffectDelay* delay_fx[NUM_DEXED];
#endif

AudioMixer<2>* delay_mixer[NUM_DEXED];
AudioEffectMonoStereo* dexed_mono2stereo[NUM_DEXED];
AudioEffectMonoStereo* dexed_dry_mono2stereo[NUM_DEXED];
AudioEffectMonoStereo* delay_mono2stereo[NUM_DEXED];

AudioMixer<2> dexed_chorus_mixer_r[NUM_DEXED];
AudioMixer<2> dexed_chorus_mixer_l[NUM_DEXED];

AudioEffectStereoPanorama ep_stereo_panorama;
AudioSynthWaveform ep_chorus_modulator;
AudioFilterBiquad ep_modchorus_filter;
AudioEffectModulatedDelayStereo ep_modchorus;
AudioMixer<2> ep_chorus_mixer_r;
AudioMixer<2> ep_chorus_mixer_l;

AudioAnalyzePeak microdexed_peak_0;
AudioAnalyzePeak microdexed_peak_1;

AudioMixer<8> reverb_mixer_r;
AudioMixer<8> reverb_mixer_l;

AudioEffectPlateReverb reverb;

AudioMixer<11> master_mixer_r;
AudioMixer<11> master_mixer_l;

AudioAmplifier volume_r;
AudioAmplifier volume_l;
AudioEffectStereoMono stereo2mono;
AudioAnalyzePeak master_peak_r;
AudioAnalyzePeak master_peak_l;
#if defined(TEENSY_AUDIO_BOARD) && defined(SGTL5000_AUDIO_THRU)
AudioMixer<2> audio_thru_mixer_r;
AudioMixer<2> audio_thru_mixer_l;
#endif

AudioMixer<2> finalized_mixer_r;
AudioMixer<2> finalized_mixer_l;

AudioPlaySdWav WAV_preview_SD;

#ifdef COMPILE_FOR_FLASH
AudioPlaySerialflashRaw WAV_preview_FLASH;
#endif

#ifdef COMPILE_FOR_PSRAM
AudioPlayArrayResmp WAV_preview_PSRAM;
#endif

// Drumset
#if NUM_DRUMS > 0

#ifdef COMPILE_FOR_FLASH
AudioPlayFlashResmp* Drum[NUM_DRUMS];
// AudioPlaySerialflashRaw*        Drum[NUM_DRUMS];  // playflash from normal audio library (no pitchshift)
#endif

#ifdef COMPILE_FOR_SDCARD
AudioPlaySdResmp* Drum[NUM_DRUMS];
#endif

#if defined(COMPILE_FOR_PROGMEM) || defined(COMPILE_FOR_PSRAM)
AudioPlayArrayResmp* Drum[NUM_DRUMS];
#include "effect_delay_ext8.h"
#endif

AudioFilterBiquad* Drum_filter[NUM_DRUMS];

// test with envelopes for samples
//AudioEffectEnvelope* sample_envelope[NUM_DRUMS];

AudioMixer<NUM_DRUMS> drum_mixer_r;
AudioMixer<NUM_DRUMS> drum_mixer_l;

AudioAnalyzePeak drum_mixer_peak_r;
AudioAnalyzePeak drum_mixer_peak_l;

AudioMixer<NUM_DRUMS> drum_reverb_send_mixer_r;
AudioMixer<NUM_DRUMS> drum_reverb_send_mixer_l;
#endif

AudioAnalyzePeak reverb_return_peak_r;
AudioAnalyzePeak reverb_return_peak_l;


//SPDIF
//AsyncAudioInputSPDIF3 spdif_in;
//AudioInputSPDIF3 spdif_in;

// Outputs

AudioOutputSPDIF3 spdif3; // enable S/PDIF by default

#if defined(TEENSY_AUDIO_BOARD)
AudioOutputI2S i2s1;
AudioControlSGTL5000 sgtl5000;
#elif defined(I2S_AUDIO_ONLY)
AudioOutputI2S i2s1;
#elif defined(TGA_AUDIO_BOARD)
AudioOutputI2S i2s1;
AudioControlWM8731master wm8731_1;
#elif defined(PT8211_AUDIO)
AudioOutputPT8211 pt8211_1;
#elif defined(TEENSY_DAC_SYMMETRIC)
AudioOutputAnalogStereo dacOut;
AudioMixer<4> invMixer;
#elif defined(TEENSY_DAC)
AudioOutputAnalogStereo dacOut;
#endif

#ifdef AUDIO_DEVICE_USB
AudioOutputUSB usb1;
#endif

#if defined(TEENSY_AUDIO_BOARD) && defined(SGTL5000_AUDIO_THRU)
AudioInputI2S i2s1in;
#endif

AudioFilterBiquad mb_filter_l_0;
AudioFilterBiquad mb_filter_l_1;
AudioFilterBiquad mb_filter_l_2;
AudioFilterBiquad mb_filter_l_3;
AudioFilterBiquad mb_filter_r_0;
AudioFilterBiquad mb_filter_r_1;
AudioFilterBiquad mb_filter_r_2;
AudioFilterBiquad mb_filter_r_3;

AudioEffectDynamics mb_compressor_l_0;
AudioEffectDynamics mb_compressor_l_1;
AudioEffectDynamics mb_compressor_l_2;
AudioEffectDynamics mb_compressor_l_3;

AudioEffectDynamics mb_compressor_r_0;
AudioEffectDynamics mb_compressor_r_1;
AudioEffectDynamics mb_compressor_r_2;
AudioEffectDynamics mb_compressor_r_3;

AudioMixer<4> mb_mixer_l;
AudioMixer<4> mb_mixer_r;

AudioConnection patchCord3(mb_filter_l_0, 0, mb_compressor_l_0, 0);
AudioConnection patchCord4(mb_filter_l_1, 0, mb_compressor_l_1, 0);
AudioConnection patchCord5(mb_filter_l_2, 0, mb_compressor_l_2, 0);
AudioConnection patchCord6(mb_filter_l_3, 0, mb_compressor_l_3, 0);

AudioConnection patchCord7(mb_filter_r_0, 0, mb_compressor_r_0, 0);
AudioConnection patchCord8(mb_filter_r_1, 0, mb_compressor_r_1, 0);
AudioConnection patchCord9(mb_filter_r_2, 0, mb_compressor_r_2, 0);
AudioConnection patchCord10(mb_filter_r_3, 0, mb_compressor_r_3, 0);

AudioConnection patchCord11(mb_compressor_l_0, 0, mb_mixer_l, 0);
AudioConnection patchCord12(mb_compressor_l_1, 0, mb_mixer_l, 1);
AudioConnection patchCord13(mb_compressor_l_2, 0, mb_mixer_l, 2);
AudioConnection patchCord14(mb_compressor_l_3, 0, mb_mixer_l, 3);

AudioConnection patchCord15(mb_compressor_r_0, 0, mb_mixer_r, 0);
AudioConnection patchCord16(mb_compressor_r_1, 0, mb_mixer_r, 1);
AudioConnection patchCord17(mb_compressor_r_2, 0, mb_mixer_r, 2);
AudioConnection patchCord18(mb_compressor_r_3, 0, mb_mixer_r, 3);

AudioAnalyzePeak mb_before_l;
AudioAnalyzePeak mb_before_r;
AudioAnalyzePeak mb_after_l;
AudioAnalyzePeak mb_after_r;

// WAV/AUDIO Recording
AudioRecordQueue record_queue_l;
AudioRecordQueue record_queue_r;
File frec;
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
void loop()
{

  // Serial read (commands from web remote)
  incomingSerialByte = 0;
  if (Serial.available() > 0)
  {
    incomingSerialByte = Serial.read();
    if (incomingSerialByte == '%')
    {
      // SD file management from remote console
      sd_filemanager();
    }
  }

  // MIDI input handling
  check_midi_devices();

  // check encoder
  ENCODER[ENC_L].update();
  ENCODER[ENC_R].update();

  LCDML.loop();

  if (touchReadTimer >= TOUCH_MAX_REFRESH_RATE_MS && touch_ic_found) {
    touchReadTimer = 0;
    updateTouchScreen();
    const TouchFn touchHandler = getCurrentTouchHandler();
    if (touchHandler) {
      touchHandler();
    }
    else if (LCDML.FUNC_getID() > _LCDML_DISP_cnt) {
      // menu
      handle_touchscreen_menu();
      scope.draw_scope(230, 18, 87, 64);
    }

    if (back_button_touch_page_check_and_init_done == false) {
      current_page_has_touch_back_button = (touch_button_back_page() || legacy_touch_button_back_page());
      if (current_page_has_touch_back_button) {
        draw_back_touchbutton();
      }
      back_button_touch_page_check_and_init_done = true;
    }

    if (current_page_has_touch_back_button) {
      handle_page_with_touch_back_button();
    }

    const ScopeSettings s = getCurrentScopeSettings();
    const bool inhibitDrawing = s.onlyDrawWhenRunning && !seq.running;
    if (s.enabled && !inhibitDrawing) {
      scope.draw_scope(s.x, s.y, s.w, s.h);
    }
  }

  if (screenSaverResetTimer >= SCREENSAVER_RESET_RATE_MS) {
    screenSaverResetTimer = 0;
    if (wakeScreenFlag) {
      wakeScreenFlag = false;
      resetScreenTimer();
    }
  }

  if (LCDML.FUNC_getID() == LCDML.OTHER_getIDFromFunction(UI_func_recorder))
  {
    if (fm.wav_recorder_mode == 1) {
      continueRecording();
    }
  }
  else if (LCDML.FUNC_getID() == LCDML.OTHER_getIDFromFunction(UI_func_seq_pattern_editor) || LCDML.FUNC_getID() == LCDML.OTHER_getIDFromFunction(UI_func_seq_vel_editor))
  {
    if (seq.running == false) {
      sub_step_recording(false, 0);
    }
  }

  if (microsynth_control_rate > MICROSYNTH_CONTROL_RATE_MS) // update lfos, filters etc. when played live or by seq.
  {
    microsynth_control_rate = 0;
    update_microsynth_params();
    // Microsynth Realtime Screen Updates

    if (LCDML.FUNC_getID() == LCDML.OTHER_getIDFromFunction(UI_func_microsynth)) {
      if (microsynth[microsynth_selected_instance].pwm_last_displayed != microsynth[microsynth_selected_instance].pwm_current && seq.cycle_touch_element != 1)
      {
        display.setTextSize(1);
        setCursor_textGrid_small(15, 18);
        display.setTextColor(GREY2, COLOR_BACKGROUND);
        print_formatted_number(microsynth[microsynth_selected_instance].pwm_current / 10, 3);
        microsynth[microsynth_selected_instance].pwm_last_displayed = microsynth[microsynth_selected_instance].pwm_current;
      }

      if (seq.cycle_touch_element != 1 && microsynth[microsynth_selected_instance].filter_osc_freq_last_displayed != microsynth[microsynth_selected_instance].filter_osc_freq_current)
      {
        display.setTextSize(1);
        setCursor_textGrid_small(15, 16);
        display.setTextColor(GREY2, COLOR_BACKGROUND);
        print_formatted_number(microsynth[microsynth_selected_instance].filter_osc_freq_current / 100, 3);
        microsynth[microsynth_selected_instance].filter_osc_freq_last_displayed = microsynth[microsynth_selected_instance].filter_osc_freq_current;
      }

      // debug
      display.setTextSize(1);
      display.setTextColor(GREY2, COLOR_BACKGROUND);
      setCursor_textGrid_small(42, 9);
      print_formatted_number(microsynth[0].lfo_delay, 4);
      setCursor_textGrid_small(42, 10);
      print_formatted_number(microsynth[0].lfo_fade, 4);
    }
  }

  if (braids_control_rate > BRAIDS_CONTROL_RATE_MS) // update  filters when played live or by seq.
  {
    braids_control_rate = 0;
    update_braids_params();
    if (LCDML.FUNC_getID() == LCDML.OTHER_getIDFromFunction(UI_func_braids))
    {
      display.setTextSize(1);
      display.setTextColor(GREY2, COLOR_BACKGROUND);

      for (uint8_t d = 0; d < NUM_BRAIDS; d++)
      {
        if (braids_filter_state_last_displayed[d] != braids_filter_state[d])
        {
          if (d >= NUM_BRAIDS / 2)
            setCursor_textGrid_small(49, 7 + d - NUM_BRAIDS / 2);
          else
            setCursor_textGrid_small(45, 7 + d);
          print_formatted_number(braids_filter_state[d] / 100, 3);
          braids_filter_state_last_displayed[d] = braids_filter_state[d];
        }
      }
    }
  }

  if (seq.running)
  {
    if (sidechain_a_active || sidechain_b_active)
      ;
    //update_sidechain();  //work in progress
  }

  if (control_rate > CONTROL_RATE_MS)
  {
    control_rate = 0;
    // glow();
    // display.fillRect(10,10,30,30, ColorHSV(1, 0, int(led_bright)));

    if (seq.running && seq.step != seq.UI_last_seq_step)
    {
      update_display_functions_while_seq_running();
    }

    // check for value changes, unused voices and CPU overload
    for (uint8_t instance_id = 0; instance_id < NUM_DEXED; instance_id++)
    {
      active_voices[instance_id] = MicroDexed[instance_id]->getNumNotesPlaying();
      if (active_voices[instance_id] == 0)
        midi_voices[instance_id] = 0;
    }

#ifdef COMPILE_FOR_FLASH
    if (WAV_preview_FLASH.isPlaying())
    {
      fm.sample_screen_position_x = fm.sample_screen_position_x + seq.wave_spacing / 10;
      if (fm.sample_screen_position_x < DISPLAY_WIDTH)
        display.fillRect(fm.sample_screen_position_x, 180, 1, 2, RED);
    }
#endif
    if (LCDML.FUNC_getID() == LCDML.OTHER_getIDFromFunction(UI_func_voice_select)) // draw MIDI in activity bars
    {
      for (uint8_t instance_id = 0; instance_id < NUM_DEXED; instance_id++)
      {
        display.console = true;
        if (midi_decay_timer_dexed > MIDI_DECAY_TIMER && midi_decay_dexed[instance_id] > 0)
        {
          midi_decay_dexed[instance_id]--;
          display.fillRect(187 + (instance_id * 12), 19, 5, 8 - midi_decay_dexed[instance_id], COLOR_BACKGROUND);                           // region above bar
          display.fillRect(187 + (instance_id * 12), 27 - midi_decay_dexed[instance_id], 5, midi_decay_dexed[instance_id], COLOR_PITCHSMP); // bar
        }
        else if (midi_voices[instance_id] == 0 && midi_decay_dexed[instance_id] == 0 && !MicroDexed[instance_id]->getSustain())
        {
          midi_decay_dexed[instance_id]--;
          display.fillRect(187 + (instance_id * 12), 19 + 7, 5, 1, COLOR_BACKGROUND);
        }
      }
      if (midi_decay_timer_dexed > MIDI_DECAY_LEVEL_TIME)
      {
        midi_decay_timer_dexed = 0;
      }
      display.console = false;
    }
    else if (LCDML.FUNC_getID() == LCDML.OTHER_getIDFromFunction(UI_func_microsynth)) // draw MIDI in activity bars on microsynth page
    {
      for (uint8_t instance_id = 0; instance_id < NUM_MICROSYNTH; instance_id++)
      {
        display.console = true;
        if (midi_decay_timer_microsynth > MIDI_DECAY_TIMER && midi_decay_microsynth[instance_id] > 1)
        {
          midi_decay_microsynth[instance_id]--;
          display.fillRect(13 * 6 + (instance_id * 12), 19, 5, 8 - midi_decay_microsynth[instance_id], COLOR_BACKGROUND);                                // region above bar
          display.fillRect(13 * 6 + (instance_id * 12), 27 - midi_decay_microsynth[instance_id], 5, midi_decay_microsynth[instance_id], COLOR_PITCHSMP); // bar
        }
        // if value is 0 then no drawing should happen - so stop at 1
        if (midi_decay_microsynth[instance_id] == 1)
        {
          display.fillRect(13 * 6 + (instance_id * 12), 19 + 7, 5, 1, COLOR_BACKGROUND);
          midi_decay_microsynth[instance_id] = 0;
        }
        if (midi_decay_timer_microsynth > MIDI_DECAY_LEVEL_TIME)
        {
          midi_decay_timer_microsynth = 0;
        }
      }
      display.console = false;
    }
  }
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

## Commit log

2021-11-22 added Touch Preview of samples
2021-11-28 fixed to fast touch input
    [touch.h]
2022-01-02 UI fixes, new arps
    [config.h, dexed_sd.cpp, sequencer.h]
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2022-01-05 UI fixes, converted Patterns to Songs
    [config.h, dexed_sd.cpp, sequencer.h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]
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2022-01-09 Fixed for User Colors
    [config.h]
2022-01-11 fix auto song lenght detection
    [config.h, dexed_sd.cpp]
2022-01-27 Major Update and fixes
    [UI.h, config.h, dexed_sd.cpp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]
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2022-04-18 revert to PROGMEM as default
    [config.h]
2022-04-23 UI, song and Arp fixes
    [MicroDexed-touch.ino, config.h]
2022-05-01 Fix interrupts
2022-05-01 Virt.Keyb. fixes, MOVED TOUCH MISO PIN
    [MicroDexed-touch.ino, dexed_sd.cpp]
2022-05-01 modified MIDI pins for PCB
2022-05-03 added wireing diagram, moved TFT DC away for MIDI
2022-05-03 fixed default value in config.h
    [config.h]
2022-05-04 modified color menu to current display
2022-05-04 converted custom drum-map and CC to current display
2022-05-07 Arpeggiator UI rebuild, small code fixes
    [MicroDexed-touch.ino, microsynth.cpp, sequencer.h]
2022-05-07 small UI fixes of old menus
    [MicroDexed-touch.ino, sequencer.h]
2022-05-14 Sequencer now can play Arps+Chords on external MIDI Gear
2022-05-14 Fix bank/voice name + usbMidi sysex
    [MicroDexed-touch.ino, dexed_sd.cpp]
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2022-05-14 added STLs
    [CASE_BOTTOM.stl, CASE_LID.stl]
2022-05-15 Fix bank/voice name if error
    [dexed_sd.cpp]
2022-05-15 small Case Lid corner fix
    [CASE_LID.stl]
2022-05-15 Fix SD card detection +warnings
    [MicroDexed-touch.ino, dexed_sd.cpp]
2022-05-15 fixed changing performance and continue playing and sysex fixes by localhero
    [MicroDexed-touch.ino, dexed_sd.cpp]
2022-05-15 Revert "Merge remote-tracking branch 'refs/remotes/origin/main'"
    This reverts commit 92a60368ceba882d2bd1400d82eeaf922e349588, reversing
    changes made to 791292fb56bd92927b0f577f22fdfe4433fca689.
    [dexed_sd.cpp]
2022-05-20 menu cleanup, image updates3
    [CASE_LID.stl]
2022-05-20 updated lid for countersunk screws
    [CASE_LID.stl]
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2022-05-22 updated STL case
    [CASE_BOTTOM.stl]
2022-05-22 updated Pin Layout for general I/O Pins on PCB
2022-05-22 added complete wiring diagram
2022-05-27 started writing instructions for latest build3
    [CASE-BOTTOM.stl, CASE-LID.stl]
2022-05-27 Added Song and Chain Data CLEAR functions
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2022-05-29 added back Multi-Sample live playback function
2022-05-29 added back Multi-Sample live playback function2
2022-05-29 added 1 missing sample
2022-05-31 Sample liveplay now plays the actual Zones from MultiSampleEditor
2022-05-31 updated STLs
    [CASE-BOTTOM.stl, CASE-LID.stl]
2022-05-31 fixed lockup of remoteconsole in samples screen
    [MicroDexed-touch.ino]
2022-05-31 added basic navigation to sampler
2022-05-31 added sample zone selection
2022-06-01 small UI additions in sampler
2022-06-01 fixed sample zone reassignment
2022-06-01 Fix root note detection
    [MicroDexed-touch.ino]
2022-06-04 MultiSample UI/Menu Enhancements
    [CASE-KNOB.stl]
2022-06-05 updated images
    [CASE_BOTTOM.stl, CASE_LID.stl]
2022-06-05 small improvements on sample editor
2022-06-06 Added new Synth_Dexed library, which adds a compressor at the end of the sound generation. Added fixes for changed method names.
    [MicroDexed-touch.ino]
2022-06-06 fixed demo patterns for flash, missing samples, some sound improvements
    [MicroDexed-touch.ino]
2022-06-06 UI reverse with touch
    [MicroDexed-touch.ino]
2022-06-06 No reverse ui by default
    [config.h]
2022-06-11 added small fix for PCM5102 Audio
    [MicroDexed-touch.ino, config.h]
2022-06-13 got QSPI working with latency issues.
    [MicroDexed-touch.ino, config.h, touch.h]
2022-06-20 fixed small array and scope issues
    [MicroDexed-touch.ino, config.h, dexed_sd.cpp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]
2022-06-24 fixed STL bottom case
    [CASE_BOTTOM.stl]
2022-06-25 fixed microsynth Noise OSC, small bBraids improvments
    [ILI9341_t3n.cpp, MicroDexed-touch.ino, config.h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]
2022-06-25 stl names
    [CASE-BOTTOM.stl]
2022-06-26 Fix Braids compilation errors
    [dexed_sd.cpp]
2022-06-26 fixed epiano UI, Touch Menu improvements
    [MicroDexed-touch.ino, config.h]
2022-06-27 fixed missing touch.h changes
    [touch.h]
2022-06-28 Fix memory issue with JSON loading
    [ILI9341_t3n.cpp, config.h, dexed_sd.cpp]
2022-07-01 Remove CV/ADC from Braids
2022-07-03 hotfix for compile issue with Teensy Audio Adaptor
2022-07-07 small #define fixes, PCB update pictures
    [ILI9341_t3n.cpp, MicroDexed-touch.ino, config.h]
2022-07-07 small #define fixes, PCB update pictures2
    [config.h]
2022-07-18 faster Volume UI and small fixes
    [ILI9341_t3n.cpp, config.h]
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2022-07-23 release 1.3.8 - added navbar, with issues
    [UI.h, config.h]
2022-07-23 release 1.3.81 - fix UI issues
    [config.h]
2022-07-24 fix small UI pixel issue
    [config.h]
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2022-08-10 added ThreadedInserts Case
    [CASE-BOTTOM(Threaded Inserts).stl, CASE-LID(Threaded Inserts).stl]
2022-08-10 updated ThreadedInserts Case
    [CASE-BOTTOM-Threaded-Inserts.stl, CASE-LID-Threaded-Inserts.stl]
2022-08-10 updated ThreadedInserts Case pictures
2022-08-11 fixed wrong MIDI channel when playing chords/arps on external MIDI gear
    [MicroDexed-touch.ino]
2022-09-15 Several replacements for getting more free RAM (especially using snprintf_P() instead of sprintf()).
    [MicroDexed-touch.ino, dexed_sd.cpp]
2022-09-15 Hotfix, revert SD File Access/Pathes empty
    [MicroDexed-touch.ino, config.h, dexed_sd.cpp]
2022-09-15 revert ff78b07295b438365c5317a51db5bb1d28fc069f
    revert Hotfix, revert SD File Access/Pathes empty
    [MicroDexed-touch.ino, config.h, dexed_sd.cpp]
2022-09-15 revert ca08d36ad89be8757b1d4bfdad538718250b9068
    revert revert ff78b07295b438365c5317a51db5bb1d28fc069f
    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
    [MicroDexed-touch.ino, config.h, dexed_sd.cpp]
2022-09-15 revert 47a489c17f84703a6193302023147877f1159784
    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
    [MicroDexed-touch.ino, config.h, dexed_sd.cpp]
2022-09-16 Menu fixes, USB Gamepad fixes
    [MicroDexed-touch.ino, config.h, sequencer.h]
2022-09-17 Again :-) Exchanged sprintf() against snprintf_P() and addded several F() functions for Serial.print*().
2022-09-17 revert 31f46c96f21fd7ec0543e7cf371eaea999269c31
    revert various menu and gamepad improvements
    [config.h]
2022-09-19 Fix struct in config
    [config.h]
2022-09-19 small fixes on mixer page
    [MicroDexed-touch.ino]
2022-09-19 Mixer with Braids and EP + fix Braids
    [MicroDexed-touch.ino]
2022-09-20 Fix routing for notes played by Braids
    [MicroDexed-touch.ino]
2022-09-21 Fix for Braids live playing
    [MicroDexed-touch.ino]
2022-09-21 Fix device for Braids
    [MicroDexed-touch.ino]
2022-09-22 Fix compilation when DEBUG is on
    [dexed_sd.cpp]
2022-09-22 mixer page encoder issue fix
    [MicroDexed-touch.ino]
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2022-09-24 Fix filename length for Flash samples
    [MicroDexed-touch.ino]
2022-09-25 added custom button support
2022-09-25 small code fixes for gamepad
    [config.h]
2022-09-28 UI and Gamepad fixes
    [MicroDexed-touch.ino, config.h]
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2022-09-30 Added Noise/Osc Filter modulation by velocity
    [MicroDexed-touch.ino, config.h, dexed_sd.cpp]
2022-10-01 Fix MIDI OMNI for Dexed and MSP
    [MicroDexed-touch.ino, dexed_sd.cpp]
2022-10-01 filter mod for microsynth
2022-10-02 fix screenupdate at msp switch
2022-10-03 prepare rework on main menu
    [UI.h, config.h]
2022-10-05 various fixes in song, pattern editor, remote console
    [config.h, sequencer.h]
2022-10-08 replaced pixel drawing of small meters with rects
    [ILI9341_t3n.cpp, MicroDexed-touch.ino]
2022-10-13 fixed some drawing issues at pixel level
    [ILI9341_t3n.cpp]
2022-10-15 Dynamic rotation + revers ui + flashmem
    [MicroDexed-touch.ino, config.h, dexed_sd.cpp]
2022-10-15 quick fix, touchscreen rotation stuck at max value
    [ILI9341_t3n.cpp]
2022-10-15 small ui fixed, game pad settings
    [MicroDexed-touch.ino, config.h]
2022-10-19 UI improvements + fix msp panbar for web remote
    [ILI9341_t3n.cpp]
2022-10-19 fix remote console processing
    [ILI9341_t3n.cpp]
2022-10-20 fixed for velocity editor
2022-10-21 resolved native key/gamepad issues
    [config.h]
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2022-11-01 small fix in midi channels page for wrong activity display
    [MicroDexed-touch.ino]
2022-11-04 braids with lfo filter is complicated to understand but starting to get usable
2022-11-05 fixed potential crash while using remote console
    [config.h]
2022-11-09 fixed/enhanced dexed delay menus
    [MicroDexed-touch.ino, config.h, microsynth.cpp]
2022-11-14 basic dexed voice editor. linked as last main menu option. no parameter sanitizing so far, eg. selecting an invalid algorithm crashes.
    [UI.h]
2022-11-16 voice editor: left encoder selects operator
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2022-11-19 error for progmem fixed
    [MicroDexed-touch.ino]
2022-11-21 small dexed editor fix, master effects page (readonly for now)
    [UI.h, config.h, dexed_sd.cpp]
2022-11-23 UI: replace dexed controllers subtree by editor page WIP (uncertain if external controllers update the UI now)
    [MicroDexed-touch.ino, UI.h]
2022-11-23 some progress in master effects page and other small fixes
    [MicroDexed-touch.ino, UI.h, config.h]
2022-11-23 filemanager: added physical back button
2022-11-23 fixed gamepad/native key issues because of menu renumbering
    [touch.h]
2022-11-23 implement long press and left encoder functions in generic UI. use for fixed dexed instance selector.
2022-11-23 handle dexed controller editor instance switching
2022-11-24 move struct UI up in the code to enable generic left encoder and long press handling for all pages using UI helper.
2022-11-24 fixed number of drumsamples, temporary fix for double increment of encoder speed
2022-11-25 added graphical and manual touch-screen calibration
2022-11-26 fixed some out of bounds values for braids and microsynth delay/reverb settings
    [MicroDexed-touch.ino, config.h, microsynth.cpp]
2022-11-27 File manager with files sorted + various fixes
    [config.h, touch.h]
2022-11-28 fixes and enhancement for delays
    [MicroDexed-touch.ino, config.h, dexed_sd.cpp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]
2022-11-30 drum UI page: new glitch free redraw on sample change
2022-12-10 Comments for Serial.print from libraries
2022-12-11 code merge, fixed delaylevel loading on startup
    [MicroDexed-touch.ino, config.h]
2022-12-12 remove control_sgtl5000plus-related UI (equalizer). We already have multiband, and teensy audio codec is no longer officially supported. But we keep it as a standard output device for now, without it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
    [MicroDexed-touch.ino, UI.h, config.h]
2022-12-12 bugfixes and enhancements pattern editor
    [MicroDexed-touch.ino, UI.h, config.h]
2022-12-17 Fix MIDI internal commands
    [ILI9341_t3n.cpp]
2022-12-17 Fix MIDI CC channel + Serial init
    [ILI9341_t3n.cpp, MicroDexed-touch.ino]
2022-12-18 Fix log + speed up boot time
    [MicroDexed-touch.ino]
2023-02-04 Switch to platformio + release folder
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2023-03-22 updated binaries, fixed braids filter mode when not set to lowpass
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2023-04-07 small enhancements in sample editor
2023-04-16 switch to lastest variableplayback
2023-05-21 fixes dexed pitch bend
2023-07-13 release 1.5.2
    [CASE-SDMOD-LID-COVER.stl, CASE-SDMOD-LID.stl]
2023-09-20 started instructions for updated display
    [LID-capacitive_touch.stl]
2023-09-22 added (internal/Teensy) USB MIDI out
2023-09-27 pin platform version to teensy@4.17 to match used C language standard
2023-10-09 buttons are edge triggered. wip on virtual synth
2023-10-09 removed display update timer, probably was broken anyways
    [config.h]
2023-10-11 add touch chip polling rate limiter. set to 100Hz what equals capacitive screen IRQ output rate.
2023-10-15 small fixes for touch-fav-button
    [touch.h]
2023-10-15 bundle draw sysex into larger (up to 512 byte) messages to avoid overhead. Needs MicroDexed-WebConsole branch bundled_draw_commands update to work.
    [ILI9341_t3n.cpp, ILI9341_t3n.h, MicroDexed-touch.ino]
2023-10-18 Fix color management in sysex + drawPixel
    [ILI9341_t3n.cpp, ILI9341_t3n.h]
2023-10-19 fix resistive repetitions by removing unneeded isr stuff
    [MicroDexed-touch.ino]
2023-10-19 touch button back enhancements
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2023-10-20 read less data from resistive touch. seems not to make things worse
2023-10-20 read only needed data for capacitive over i2c
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2023-10-21 Fix drawPixels sent when terrain is active on mdt
    [ILI9341_t3n.cpp]
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2023-10-22 added use of touch rotation value from config to new capacitive screen
2023-10-24 fix for my 3.2 inch capacitive touch using configuration.sys.touch_rotation=1. change if-else to switch-case since faster and better readable
2023-10-24 fixed favorite button while virt.keyboard is on screen
2023-10-29 small fix page background colors
    [MicroDexed-touch.ino]
2023-10-31 small fix for octave printing
2023-11-04 added SLA 3dprints
    [microdexed-BOTTOM-sla.stl, microdexed-LID-capacitive_touch-sla.stl]
2023-11-15 workaround unreliable boot with CAPACITIVE_TOUCH_DISPLAY and PSRAM defined
    [MicroDexed-touch.ino]
2023-11-15 fix screensaver direct access to touch driver
2023-11-15 update texts and images
    [BOTTOM-capacitive_touch.stl, LID-capacitive_touch.stl, microdexed-BOTTOM-sla.stl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]
2023-11-17 keepWakeFlag for any midi noteOn. slower timer reset based on wake flag. fast screensaver rendering, seems to not use any more measurable cpu. cleanups.
    [MicroDexed-touch.ino, UI.h, screensaver.h]
2023-11-17 undo horizon brightness fade for now, gave issue on screensaver fade time
    [screensaver.h]
2023-11-26 release 1.6.4 - latch fixes
    [MicroDexed-touch.ino, UI.h]
2023-12-05 skip touch when not present
    [MicroDexed-touch.ino, dexed_sd.cpp]
2023-12-06 small fix: resistive touch was broken
    [MicroDexed-touch.ino]
2024-02-02 LiveSequencer (#170)
    This adds a Live Sequencer implementation to MDT:
    ---
    Quick howto:
    1. define 6 instruments to tracks 1 - 6 in song view. Assign all different MIDI channels (also for your keyboard, events are forwarded)
    2. open "Live Sequencer" in Sequencer menu
    3. a simple drum track layer is added automagically to have some tempo
    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
2024-02-13 fix: readded reaction to bpm and track changes
2024-02-13 small bugfixes for saving/loading values
    [MicroDexed-touch.ino, config.h, dexed_sd.cpp]
2024-02-15 further fixes for Drum Page
    [MicroDexed-touch.ino]
2024-02-18 also quantisize mute events when song recording using track's quantisize setting
2024-03-02 arp with own timer for more live possibilities
2024-03-09 possible to jump to midi mapping from livesequencer channel map warning. fix compressor always diasabled before calling handleStart
    [MicroDexed-touch.ino, ui_livesequencer.h]
2024-03-19 fixes for MIDI SYSEX Transfer Path issues
    [dexed_sd.cpp]
2024-04-02 UI fixes and new touch button in dexed voice page
    [config.h]
2024-04-03 live and arp timers are TCK and a new precise GPT timer makes call tick
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2024-04-09 sample keys a number of times per bar. latch off behavior not yet good
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2024-04-24 release 1.6.82
    [drumset.cfg]
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2024-05-05 basically can source arp notes from track too
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2024-05-10 fix occasional live sequencer crash on performance load when sequencer running
    [dexed_sd.cpp]
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2024-05-10 get remote console back drawing correctly
    [ui_livesequencer.h]
2024-05-10 fix progress bar on MDT..
    [ui_livesequencer.h]
2024-05-11 fix fill notes while running crashes. apply arp mode and octaves also without new notes latched in. correctly sort multi-octaves UPDN/DNUP/.. mode notes. fix: new added layer could be muted initially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
    [MicroDexed-touch.ino]
2024-05-13 fix note remained on when arp from track and arp enabled while note was playing
2024-05-14 fix active arp noteOff on wrong track when changing track while arp is playing
2024-05-24 fix pages opened from livesequencer got overdrawn onStopped. keep processing midi in for all pages opened from here
    [ui_livesequencer.h]
2024-05-24 fix tick timer too slow and not triggering events just at end of pattern reliably
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2024-05-25 also adapt velocity for incoming midi events from keyboard
2024-06-07 support button long press. needed to refactor handleTouchScreen for my screen as it is/was called way too fast.
    [MicroDexed-touch.ino, touch.h, ui_livesequencer.h]
2024-06-12 liveseq editor better scrolling, UI fixes, better stability
    [MicroDexed-touch.ino]
2024-06-14 fix open emtpy livesequencer when sequencer is running crashed
    [dexed_sd.cpp]
2024-06-14 delay all arp events by 1ms to make sure when in track source mode, quantized notes are already on when sampling
2024-07-04 dexed chorus and small fixes
    [MicroDexed-touch.ino, config.h]
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2024-08-02 track setup now only shows existing MDT instruments in selection
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2024-08-02 always have track setup selection and last pressed note up-to-date when opening its tools. show active track number for track setup
2024-08-02 also save track velocity and arp settings to non-volatile performance data
2024-08-02 fix: load perf now pre-selects current performance instead of performance 0 in livesequencer
2024-08-06 ...now really updating track instrument buttons correctly
    [ui_livesequencer.h]
2024-08-09 default sample fixes
2024-08-10 separate drum sample displayname and filename. reduce code redundancy.
2024-08-10 fix sample name not completely shown in drum screen
2024-08-10 no need to specify sample size for PROGMEM samples when using sizeof
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2024-08-13 fix CUSTOM sample paths. now it crashes again :)
    [MicroDexed-touch.ino]
2024-08-13 without PSRAM it seems load load all samples
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

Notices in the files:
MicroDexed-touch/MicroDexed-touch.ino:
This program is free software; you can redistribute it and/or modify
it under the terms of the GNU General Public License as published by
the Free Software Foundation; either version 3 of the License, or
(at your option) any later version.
